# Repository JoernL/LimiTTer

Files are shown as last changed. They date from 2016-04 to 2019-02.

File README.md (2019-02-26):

# LimiTTer
Transmitter for the Freestyle Libre FGM system

With the LimiTTer you are able to transform the Freestyle Libre FGM system into a real
Continous Glucose Monitoring System (CGMS). That means that you don't have to manually
scan the sensor with the reader. The LimiTTer does this for you - every 5 minutes. It sends
the glucose value to your smartphone which must have the xDrip app installed. xDrip is really
a great and matured app for Android. It can send the glucose values to your smartwatch or
via Nightscout into the cloud. The most important feature is to having a night guard.
xDrip+ is an improved version of xDrip and now the default app for the LimiTTer.
You will find it here:</br></br>
<a href="https://jamorham.github.io/#xdrip-plus">https://jamorham.github.io/#xdrip-plus</a></br><br>
Click on "Download latest APK" or choose the "Nightly Snapshots" for the very latest ones.

Please note, that LimiTTer is NOT maintained by Abbott. It is a experimental DIY project.
You will built your own individual LimiTTer. So you are responsible yourself for what you
have built. I have opened this project here because it's a invitation for all developers
out there to improve the LimiTTer.

Feel free and join our chatroom here: 
***









***

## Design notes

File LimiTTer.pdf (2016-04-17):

DISCLAIMER: LimiTTer is a experimental DIY project. By building your own transmitter, you are responsible yourself for what you have done. The authors and maintainers of this project cannot be made responsible for any damage or actions.
Don't make any medical decisions based on the data of your sampled device.

Please Note: LimiTTer is not maintained by Abbott. It's only an experimental DIY guide.

Let's get started.

You will need the following things:

- Libre Reader (for starting a new sensor)
- Arduino pro-mini 3V 8Mhz
- USB to TTL Serial Adapter Module
- Solutions Cubed BM019 NFC Module
- HM-11 Bluetooth Module (Seeedstudio)
- Lipo battery >= 3.7V 220mAh 40x17x6mm (When BLE OFF enabled, 100mAh suffices)
- Lipo charger (Adafruit Mini micro-usb)
- Small power switch
- A box 40x40x12mm
- AWG 30 silicone-cable
- Soldering iron
- Helping Hand
- 2K epoxy glue
- Dremel like multitool with grinding wheel

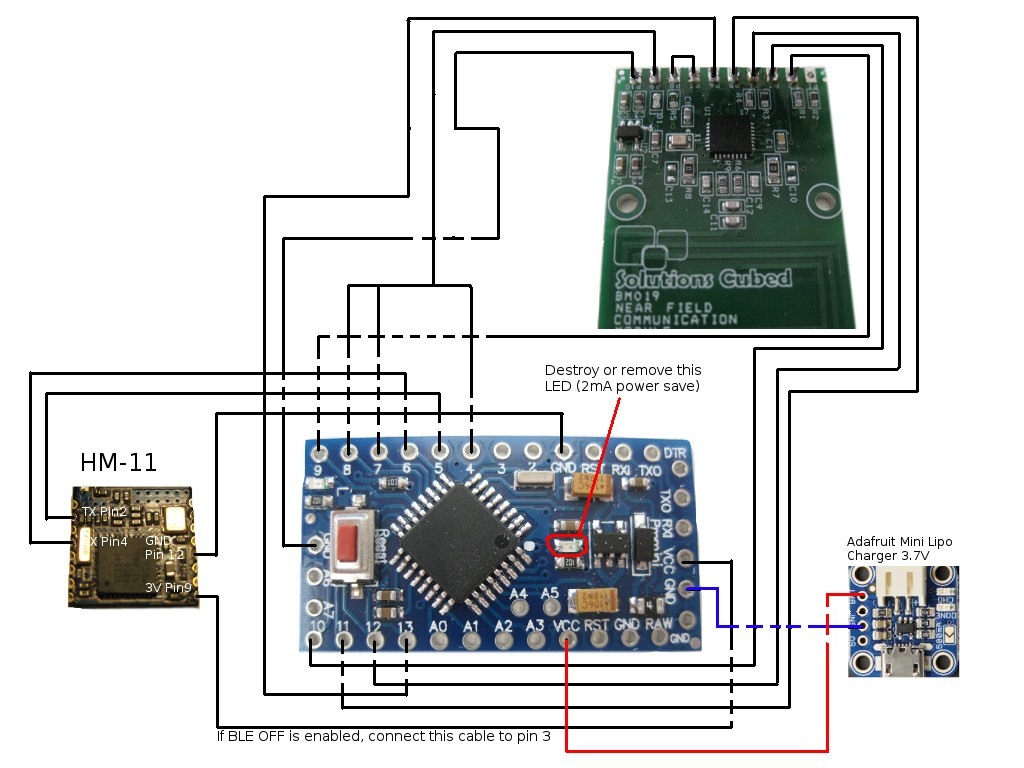
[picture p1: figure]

You may wonder why pin 4,7,8 are going into the Vin of BM019. It's because i need to power off this module completely and when it wakes up for reading and spi comes up, the power consumption raises to 80mA. So i just split this into 3 ports to spare the Arduino.

First download LimiTTer.ino and save it to your desktop.
Then you have to download and install the Arduino IDE. You will find it here:

https://www.arduino.cc/en/Main/Software

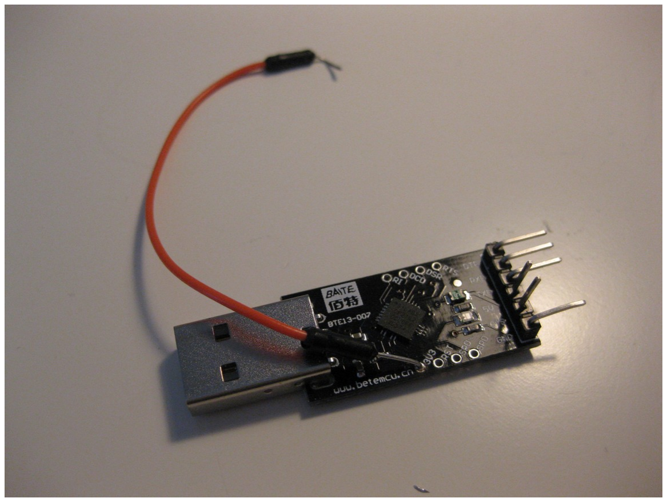
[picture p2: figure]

Start the IDE and navigate to the tools → board menu. Select „Arduino Pro or Pro Mini. From „Processor“ choose „ATmega328 (3.3V, 8MHz)“.
Now open the LimiTTer.ino file and prepare your Arduino:

Solder a cable to the 3V3 pin and bend up the 5V and CTS pins.

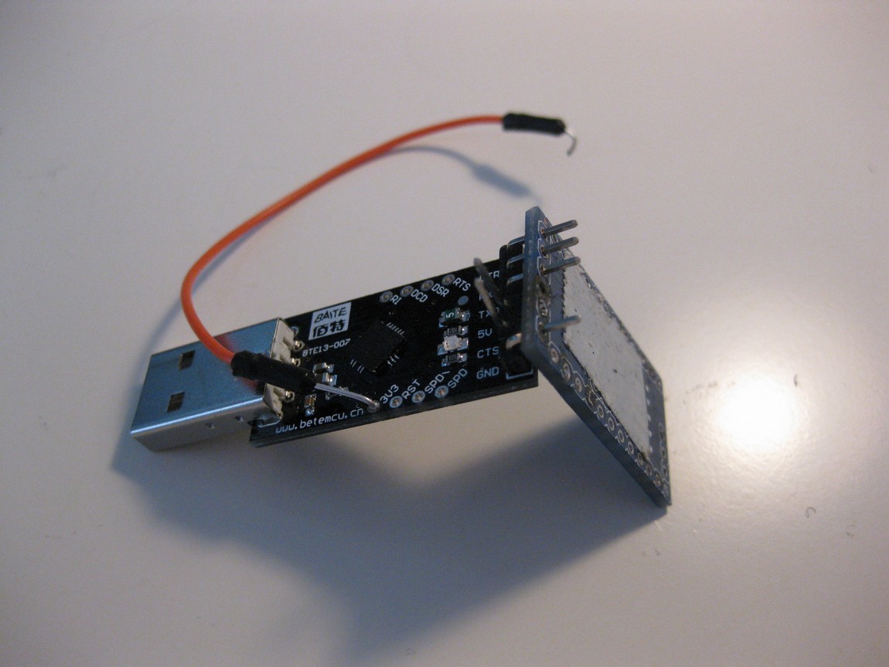
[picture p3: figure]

Plug the adapter into the Arduino and connect it with the USB jack
to your computer. Now you are ready for program the board. Click on the Upload button and hold the 3V wire on a VCC pin of the Arduino. Yes, it's a bit tricky. Of course you can temporarily solder it on that pin ;) When there is no error message and you see „Done uploading“ you can pull it out of the computer.

Now the hardware:

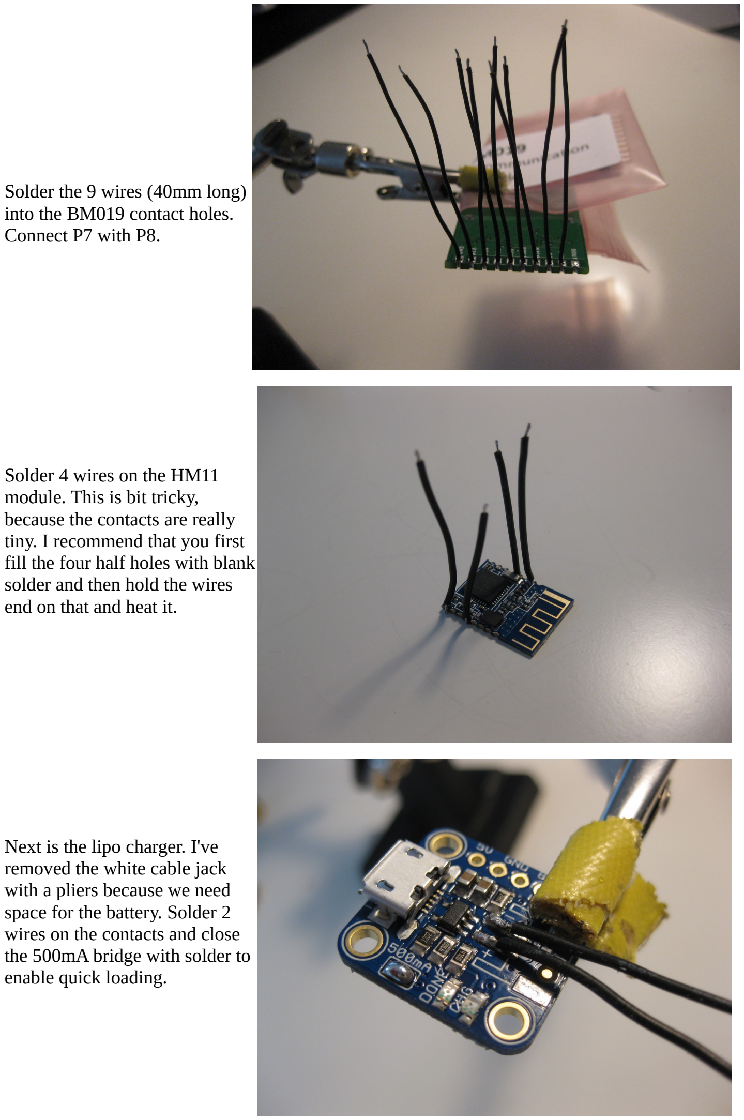
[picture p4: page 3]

Solder the 9 wires (40mm long) into the BM019 contact holes. Connect P7 with P8.

Solder 4 wires on the HM11 module. This is bit tricky, because the contacts are really tiny. I recommend that you first fill the four half holes with blank solder and then hold the wires end on that and heat it.

Next is the lipo charger. I've removed the white cable jack with a pliers because we need space for the battery. Solder 2 wires on the contacts and close the 500mA bridge with solder to enable quick loading.

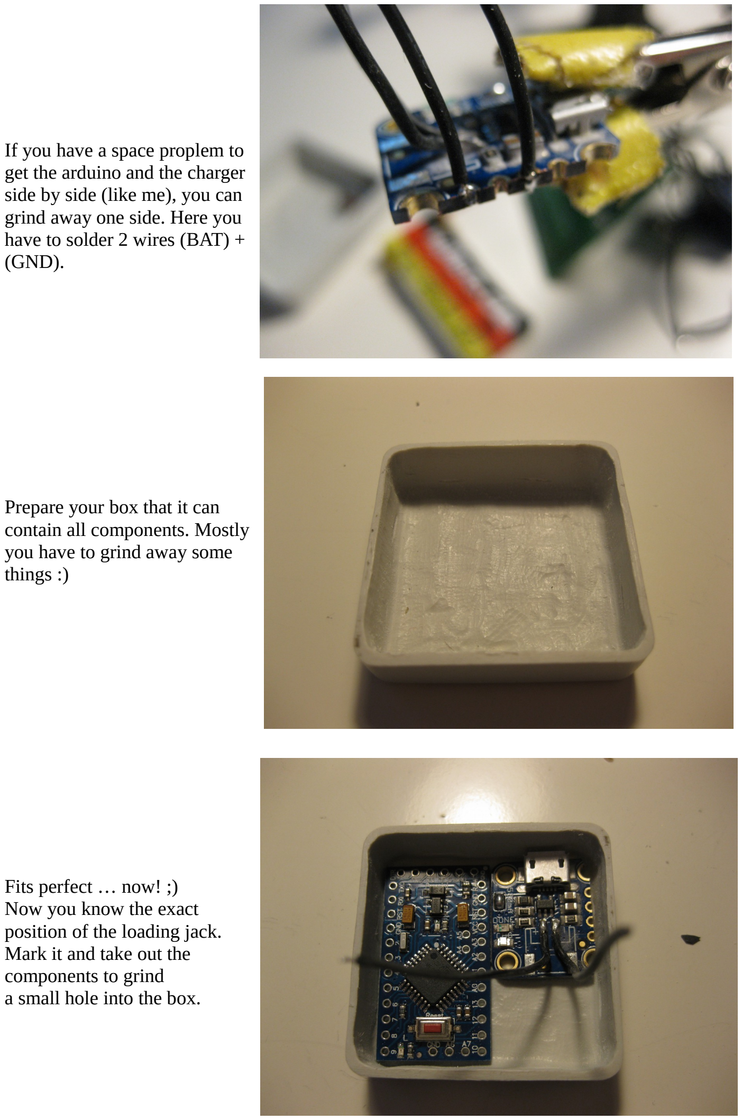
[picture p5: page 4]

If you have a space proplem to get the arduino and the charger side by side (like me), you can grind away one side. Here you have to solder 2 wires (BAT) + (GND).

Prepare your box that it can contain all components. Mostly you have to grind away some things :)

Fits perfect … now! ;)
Now you know the exact
position of the loading jack. Mark it and take out the
components to grind
a small hole into the box.

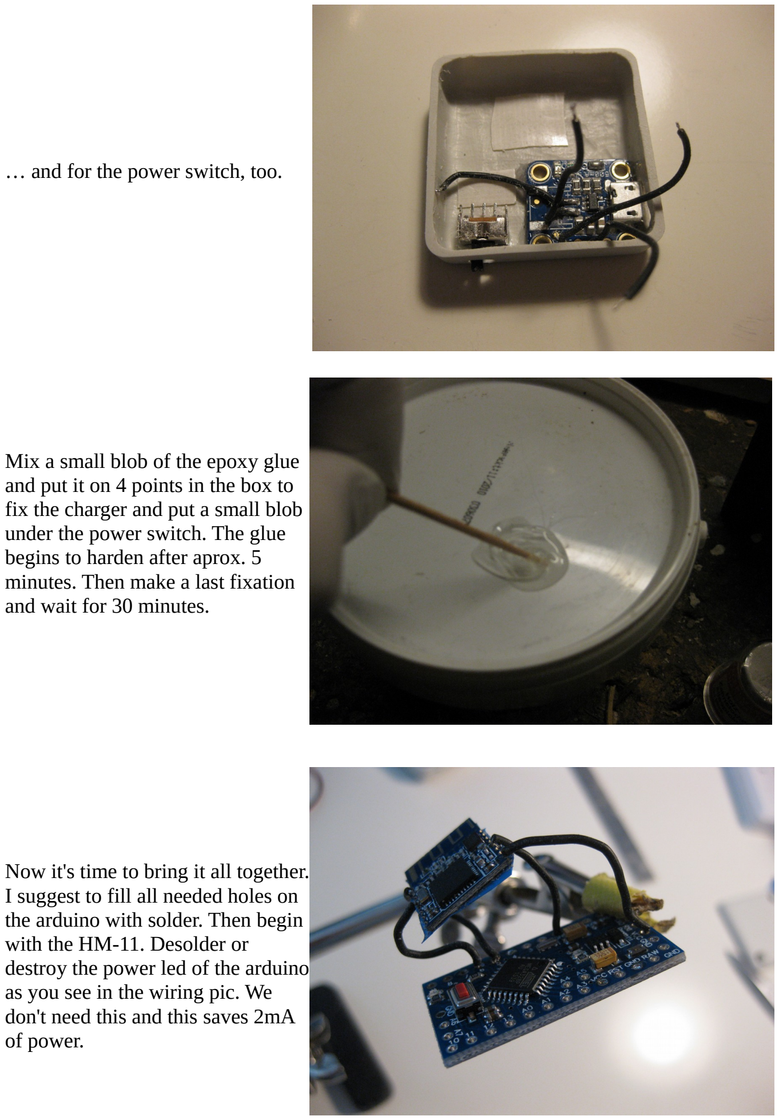
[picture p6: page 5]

… and for the power switch, too.

Mix a small blob of the epoxy glue and put it on 4 points in the box to fix the charger and put a small blob under the power switch. The glue begins to harden after aprox. 5 minutes. Then make a last fixation and wait for 30 minutes.

Now it's time to bring it all together. I suggest to fill all needed holes on the arduino with solder. Then begin with the HM-11. Desolder or destroy the power led of the arduino as you see in the wiring pic. We don't need this and this saves 2mA of power.

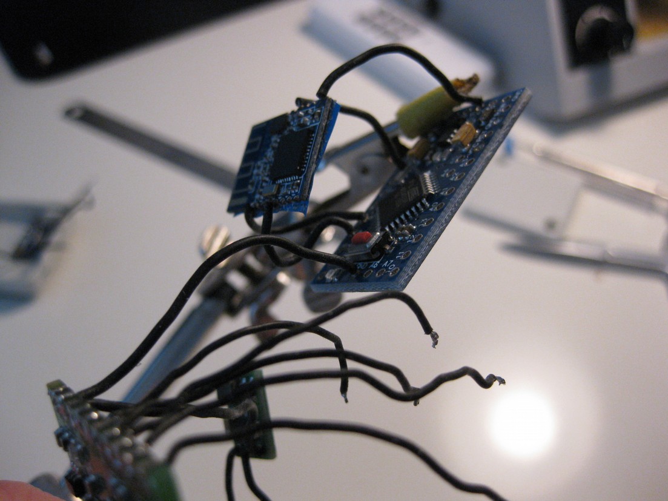
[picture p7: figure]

Then go on with the NFC module.

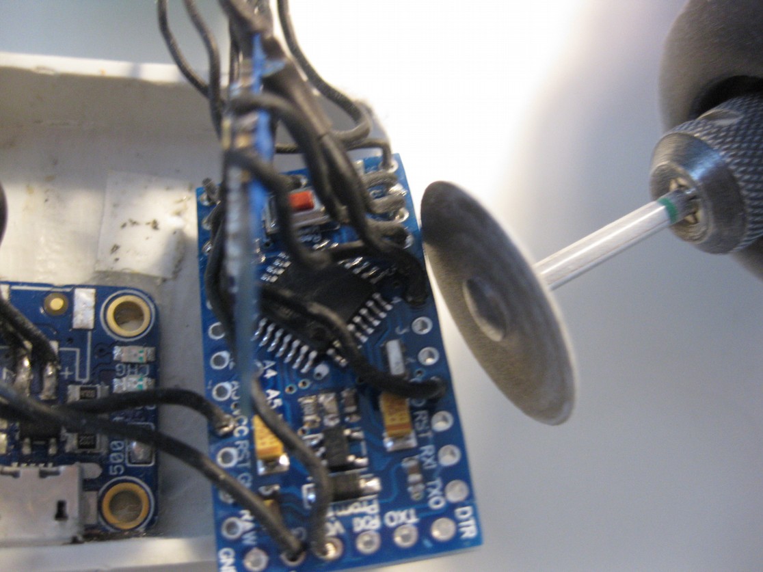
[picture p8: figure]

And now the lipo charger … You can grind the sides of the Arduino, if you have a space problem (like me).

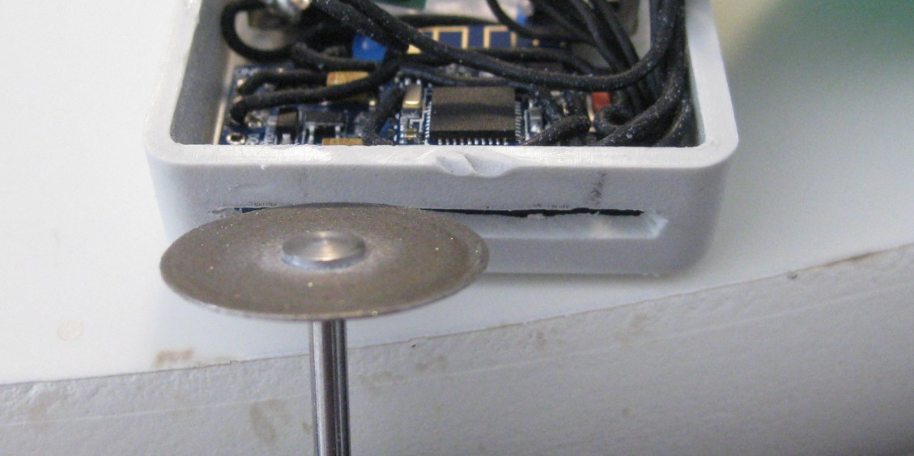
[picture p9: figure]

All 4 PCB's are now wired together. It's time for the recess.

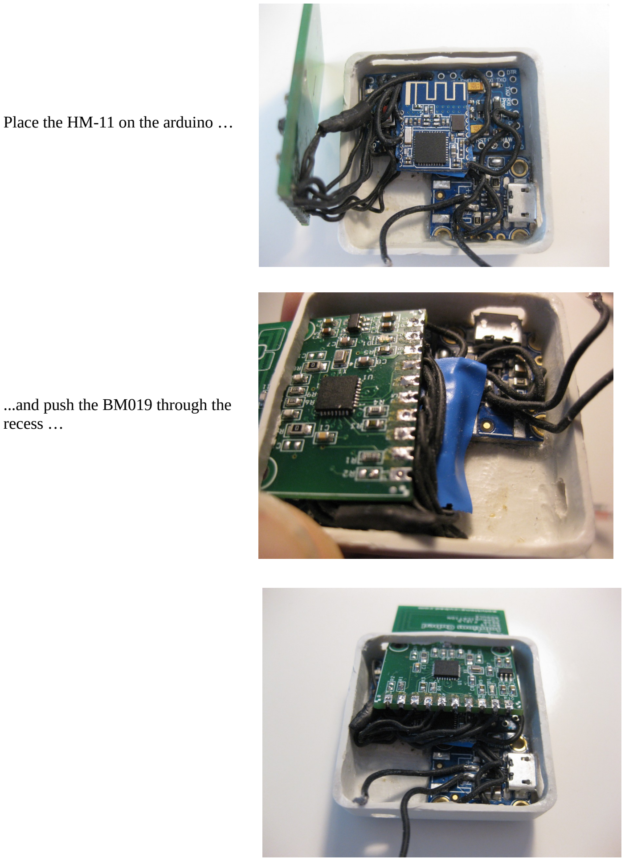
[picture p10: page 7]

Place the HM-11 on the arduino …

...and push the BM019 through the recess …

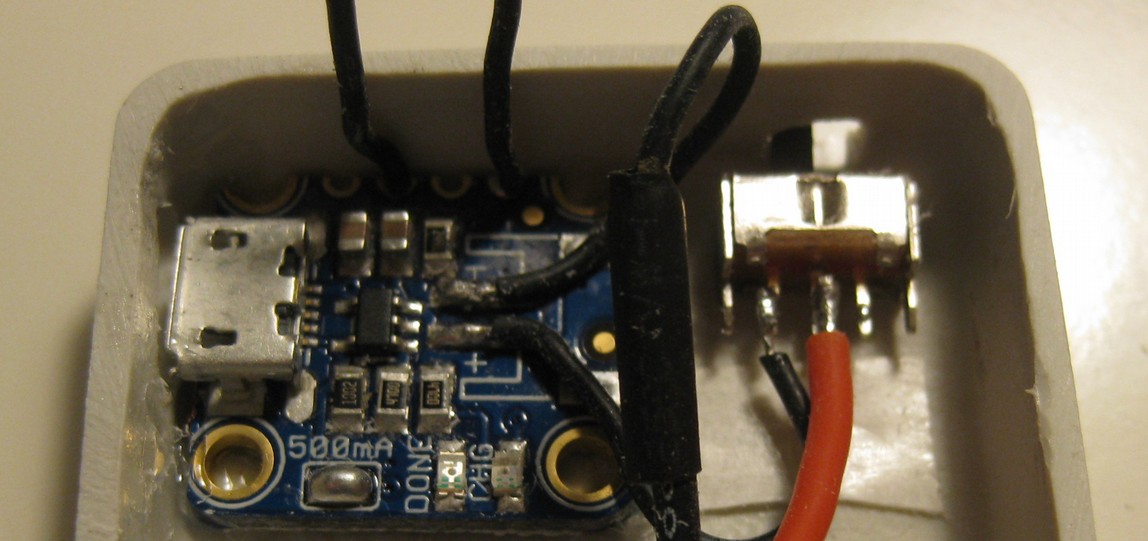
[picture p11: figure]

Solder the Lipo to the switch

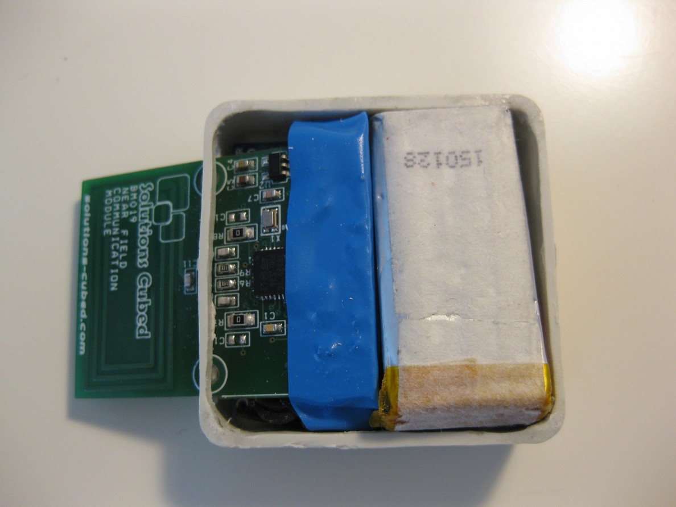
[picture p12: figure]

...and place it on the charger/ switch

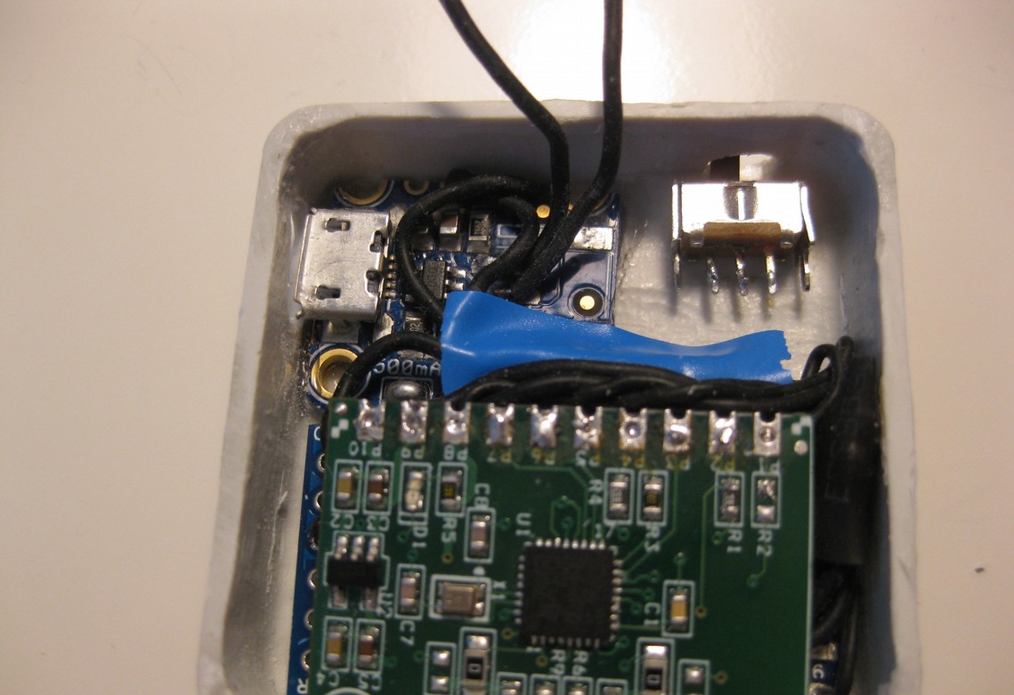
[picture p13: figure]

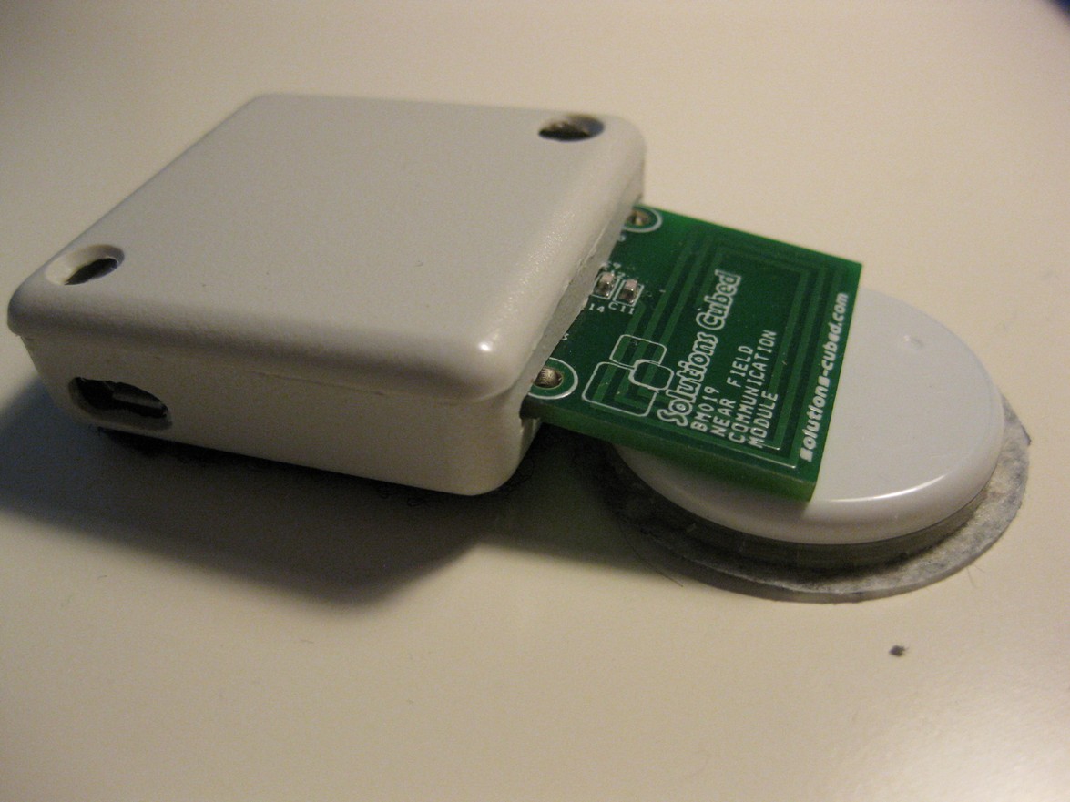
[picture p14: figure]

Close the box and fix the
lid with superglue on it's corner points. Add only tiny blobs of the glue.

To place and fix the LimiTTer on your skin near the sensor you can use Velcro tape or the very thin dual lock from 3M.

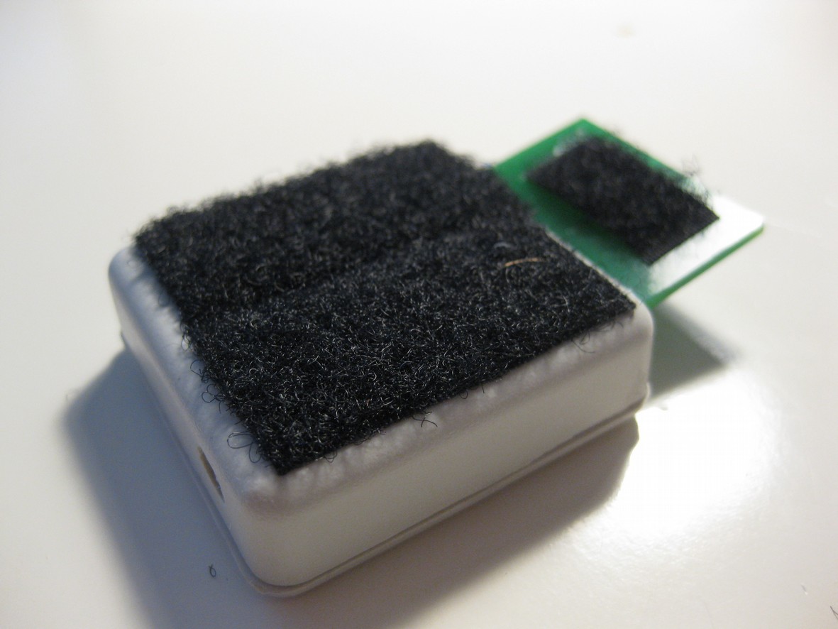
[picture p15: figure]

Turn on the power switch and place it near the sensor.
Finally download and install xDrip. You will find it here:

https://github.com/StephenBlackWasAlreadyTaken/xDrip/wiki/xdrip-beta

Download and install the latest beta .apk file. Maybe you have to enable the option to install apps from a unsave source.

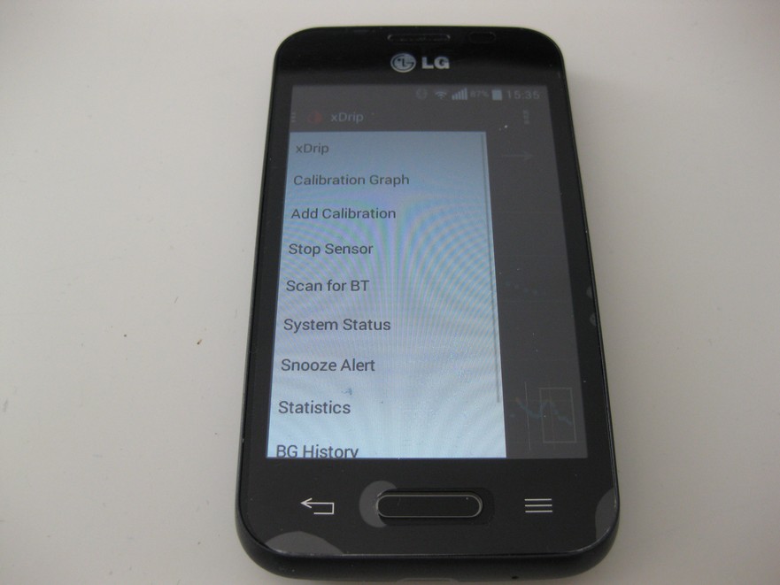
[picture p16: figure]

Then activate bluetooth on your smartphone and start xDrip. Click on the xDrip menu (left upper corner) and select Scan for BT.
Click on scan and you should see your box. If you don't see it, there is something wrong with your wiring … or you are using the BLE OFF wiring. Then it sleeps and will wake up the next 4 minutes … check it out and tap on scan several times.

Tap on LimiTTer and it will connect to it. After this you have to tap on Start Sensor. Just select a few hours in the past to avoid the 120minutes waiting. We don't need this. Now xDrip waits for 2 readings (10 minutes). When they are received you will see

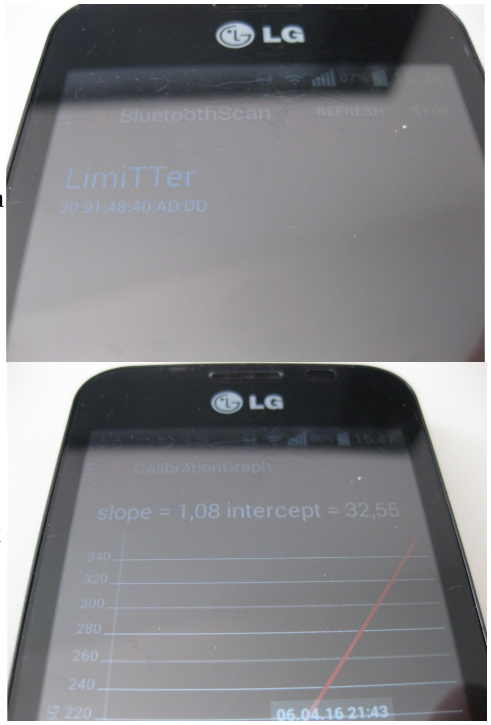
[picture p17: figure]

Enter 2 Calibrations. Tap on the menu and then on Add double Calibration. Enter your glucose value twice and tap on Done. Now xDrip should show you every 5 minutes a value.

Acquaint yourself with xDrip. It's a great and matured app with many features.
Have a look at the Settings Menu. With xDrip you can set an offset to the gluco value. That means if you know the difference between the libre reader and your real gluco from your meter, you can check the Calibration Graph and check the intercept value. As a sample my reader mostly shows a value that is -30mg/dl compared to my meter value. My intercept is 32.55. That means xDrip calculates
+32.55 to that value coming in from the LimiTTer
and then display it. You can change the intercept
with Add Calibration. So when you have entered a calibration
and checked the intercept and it doesn't match yours, tap on Override Calibration, re-calculate the value and check the intercept again.
When you take off the transmitter for charging and apply it again it is sometimes necessary to tap on Forget Device in the System Status menu. After this you have to Scan for BT and tap on LimiTTer again to reconnect the device.

The LimiTTers power consumption is 8.8mA @ sleep because Bluetooth is always on. With a 220mAh lipo you must load it every 24hrs. Charging time: about 40-45min. If you have Android >= 5.x you can try to solder the BLE OFF circuit and enable all lines in the Limitter.ino file that contains BLE OFF. Have a look to the sketches description. The problem is the reconnect after turning off Bluetooth completely. With that circuit, power consumption is 0.16mA @ sleep for 4 minutes. Then it wakes up and waits 60sec for the reconnect. If this works stable for you, then you can use a smaller lipo (80-100mA) and reduce the heigth of the box. (2-3mm thinner).
So check it out ...

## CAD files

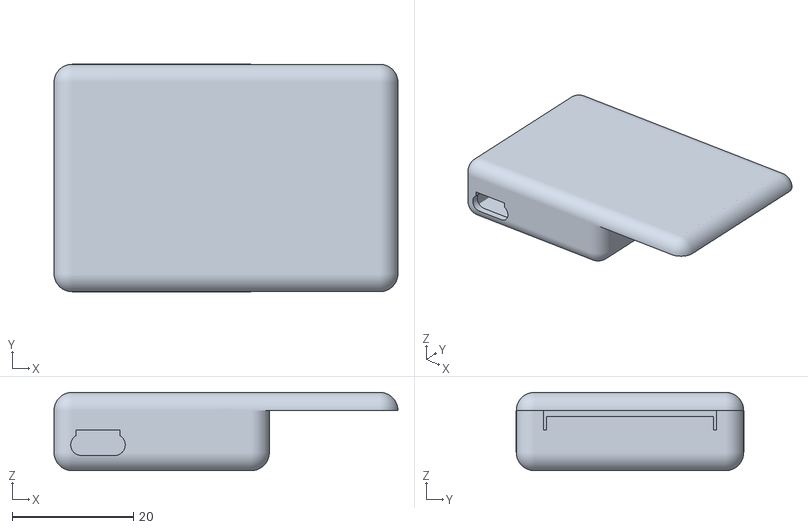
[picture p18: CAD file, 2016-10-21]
case-3dprint/case_assembly.stl
56.7 x 37.5 x 12.9

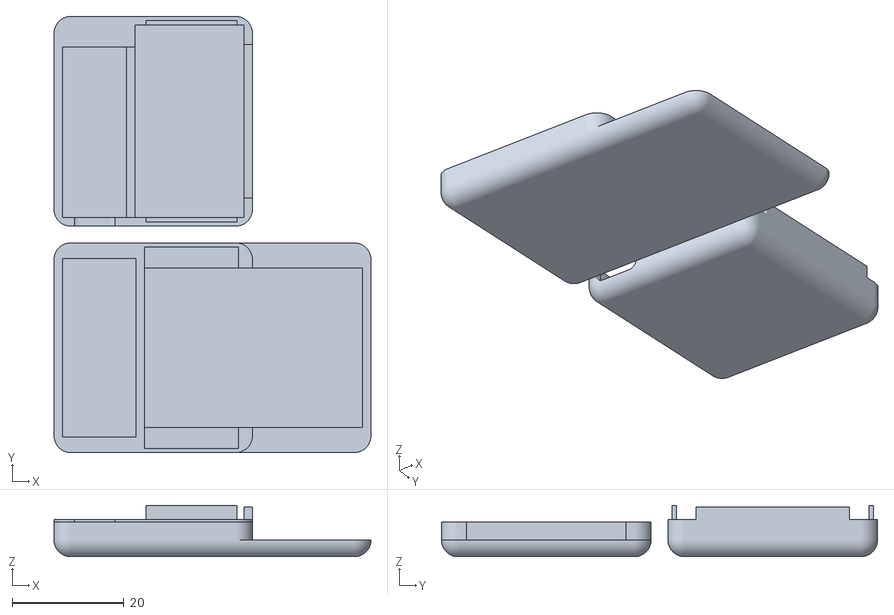
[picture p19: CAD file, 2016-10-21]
case-3dprint/case_print.stl
56.7 x 78.0 x 9.20

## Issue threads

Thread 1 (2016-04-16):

LIMITTER

pedrojrr, 2016-04-16:
Hola mi nombre es Pedro y soy padre de un niño Diabetico que usa el freestyle libre. Primero quisiera darle mi enhorabuena por el desarrollo del proyecto ya que llevábamos tiempo buscando algo parecido.  Estoy deseando que comparta su diseño para poder probarlo en mi hijo sobre todo por la utilidad de guardián nocturno.  Gracias por su tiempo y dedicación estoy convencido que seremos muchos los padres que se lo agradeceremos. Espero tener pronto noticias suyas

holmberg81, 2016-04-16:
English would be more easier to understand.

berniemcintosh, 2016-04-21:
I speak a little spanish - here is a rough translation:

Hi, my name is Pedro and I am the father of a Diabetic boy that uses the Freestyle Libre. First I want to give my congratulations for developing the project since we have been waiting some time for something like this.  I want you to share the design for us to be able to use it with my boy, above all, for the overnight watch. Thanks for your time and dedication. I am convinced that there will be many of us parents that thank you. I hope we have more updates from you soon.

JoernL, 2016-04-21:
@berniemcintosh , you are welcome.

JoseRobotnik, 2016-04-24:
Congratulations for developing such as great project.
I ordered some of the components of the limitter in aliexpress.com, except the BM019 NFC2Serial. Is there any other NFC2serial compatible dongle to replace it?
Many thanks

JoernL, 2016-04-24:
I dont't know any other working module.

libxmike, 2016-04-26:
Joern, is there any trick to pair with Android?
I have Nexus with Android 6 and can't pair, not with the default pin or any other,
can't see it in xDrip, any ideas?

To see the name "Limitter" in Settings-> BT, I had to change the code to:
ble_Serial.write("AT+NAMELimitter");

JoernL, 2016-04-26:
Settings -> Apps -> xdrip -> permissions. Enable location services.

tim2000s, 2016-04-26:
Thanks Mike. I'll try that. I can see the HMSoft device in xDrip without that mod and it pairs, although it didn't transmit any data. Do you have the correct baud rate set?

Sent from my iPhone

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

birdfly, 2016-04-26:
Hello,I  am a T1D for six years and user of a free style libre,I just  wonder that LimiTTer(the hardware )could interpretate the Tag-data  or transmit  the raw data to xDrip directly.For I have used several libre apps ,the value they read are different from the official reader.

tim2000s, 2016-04-26:
Okay, my progress so far is that I've built the LimiTTer, and that all the components communicate. I can confirm the Arduino is speaking to the HM10 as, with the earlier tweak, I was able to get the module renamed correctly.

The assembly then connects to xDrip on the phone successfully.

At the five minute intervals, the NFC card comes to life and I am assuming it scans, and I see the green LED flash on the Arduino. What I don't get is anything in xDrip. Nothing is showing up.

I welcome any ideas on what I might need to change. The baud rate is set to 9600 as is the default on my HM10. Just not picking anything up and transmitting it.

Sent from my iPhone

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

JoernL, 2016-04-26:
You are not able to start a sensor in xdrip? The 2 start readings don't come in?

tim2000s, 2016-04-27:
That's right. Whilst xDrip sees the Bluetooth and connects, and I see the BM19 trigger, I'm not seeing anything come in on the two start readings. I'm running android 5.1.

Sent from my iPhone

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

JoernL, 2016-04-27:
The Hardware Data Source in xDrip settings must be set to "Bluetooth Wixel". Maybe you have changed this?

JoernL, 2016-04-27:
@birdfly  as yet, it only reads the last saved reading from the sensor and send it to xDrip, which modify the raw value through a slope and an intercept and then displays it at it's graph. I'm working on it now to find out how the original reader can precalculate the readings when glucose rising fast? At this moment the raw reading is the nearly the same but the LibreReader shows a very higher value. Maybe a hidden dynamically slope multiplier in the tag? Didn't find it yet.

berniemcintosh, 2016-04-27:
Joern,

I commend your work and find it most interesting.  My own feeling is that I think I prefer to see a raw reading from the Libre, with a simple adjustment to put it into mmol/ml. I think the need for predictive algorithms is perhaps not as great as the stress that some put on them.

My take on it is that knowledge and context are the most important thing. I know that the interstitial glucose level lags behind BG as measured with a finger stick. This in itself lags behind venous level. Just as we are all used to the lag in BG fingerstick readings, maybe we should all get used to the lag in interstitial readings.

If I see that the Libre raw reading is fairly constant, then I can have good confidence that it reflects the reality. Constantly high, maybe I need to take a small amount of insulin. Level of 4.0 for half an hour and I'm about to exercise then maybe a little glucose is in order.

If the Libre reading is rising fast, I can judge for myself if there is a single reading that is a little out of step or if there is a trend. If there is a trend, then I can see how sharp the trend is, and for how long it has been there. I can look a the picture and let my brain fathom it  out using its massive parallel processing power and pattern recognition abilities in order to understand what is happening. An actual, predicted level that matches a BG fingerstick I don't believe is my ultimate objective. I can guess at what it might be and it will probably be as correct as any complex multiple derivative based algorithm.

Perhaps the trouble with the algorithm is you don't quite have a grasp of what the algorithm has done. At least with raw data I can use my experience.

Likewise when BG is dropping. I see that the raw data is plunging from 13 to 10 to 7 to 5 in 25 minutes. I think I'm not concerned that I don't have a predictive current value equivalent to BG fingerstick. I want  some glucose please, NOW. Even though it says 5.  My experience tells me what is going to happen next. Not that I have such dramatic incidents too often, but it can happen.

So adjustment of data with slope and intercept yes, but predictive algorithm like the built in one - kinda looks good but not necessary.

As you know occasionally the Libre refuses to give you a reading.  Wouldn't you just love to know what the raw values are that led to that decision. Well I guess we do now with the BM019 but I've yet to see it for myself.

Sorry - not trying to put you off - its good to have a predictive algorithm too. The more info the better. J

Cheers

Bernie

tim2000s, 2016-04-27:
Definitely set to the correct source. That's what is so odd.

Sent from my iPhone

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

SugarBots, 2016-04-27:
Tim- have you tried using a Bluetooth tool like Adafruit Bluefruit LE or BLE ( I use the ones for iOS) to confirm the BLE packets?
And have you successfully paired the BLE in both android settings and xDrip? I haven't had issues with getting the data to display on xDrip, just that the mmol conversion needed to be added in.
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
tim2000s, 2016-05-02:
Update: For some reason after a restart, it is working. I'm getting data on xDrip from a live Libre sensor.

Sent from my iPhone

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

libxmike, 2016-05-02:
@tim2000s what did the magic?
I slowly give up, my stick with my working Simblee solution and iOS app.

JoernL, 2016-05-02:
@tim2000s, i think it will. But the modules length is 43mm. I've chosen the pro-mini because its only 32mm. Every mm counts ;) It must be as small as possible cause you wear it every time.

JoernL, 2016-05-02:
@libxmike, tomorrow i will upload new code. Maybe this will fix your problem.

libxmike, 2016-05-03:
@JoernL thanks, will be great if it works, and thanks for your time you investing in it.

sean75, 2016-05-03:
Dear Sir,
I write from Italy, south Italy,and my son is a diabetic boy ten years old.
He use frestyle libre and I have a lot of interest for limitter.
Can you give me some information to build it?
Sorry for my bad english.
Thanks
--
Inviato da Libero Mail per Android martedì, 03 maggio 2016, 07:24AM +02:00 da libxmike < notifications@github.com> :

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

tim2000s, 2016-05-03:
I think it depends on how you wear it. If it's in a neoprene sleeve, fewer devices and lying next to the BM19 is fine.

I'm trying to avoid the box!

Sent from my iPhone

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

tim2000s, 2016-05-03:
Look forward to this!

Sent from my iPhone

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

LibCGM, 2016-05-03:
@tim2000s box is not an optimal solution, I designed and 3D printed one, it is too bulky
http://imgur.com/8nMsZuy
I may design one with round edges, shallow/flat and reassembles you arm - arc shape, the frame is 1-1.5mm thick

SandraK82, 2016-05-03:
we are exploring the option to use flexible boards embeded in Silikone for the bluereader. The only bad thing is, that firmware over the air has to work correct, or the Silikone must be openend. Loading will be wireless, probably qi std. Batteries might be two rechargable li-ion coins cells
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

LibCGM, 2016-05-03:
@SandraK82 Silicone my be the same problem as Abbott glue, maybe warped in a fabric to avoid Silicone - skin contact? but again it wont be on 24/7 like the Sensor so you skin can breath.
Silicone is ok if you want to have it on 24/7 w/o taking it off, Qi charging was also my consideration but in addition to micro USB in case you are not near a charger. It has to be moist but not waterproof, you don't want to swim or shower with it.

SandraK82, 2016-05-03:
Yes it might be, but so far it seems to be the best option we can think off. For the usecase as libre reader, the solution does indeed not be waterproof, however we are targeting a broader audience (like Industrie) with the bluereader. Therefore it needs to be resistente against Shock, fluids, chemicals and needs a a easy handling.
My current protoype setup is only warped in  insulation tape and needs a 5v breaboard Adapter for charging (currently no lipo charger with usb port, order does not arrive). I found fixing the the board with medical tape (Leukosilk) works best for me. I applied a curapor plaster over the sensor to further protect my skin ( i got burns from an unprotected contact of my boards once). I Experimente also with arm cases for mp3 players, bandages and a custom sawn armband but i was not able to lock the board over the sensor for a day without squeezing my arm to tight.

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

tim2000s, 2016-05-03:
I'd been looking at the flexible PCB options too.

The issue I'm running into with all of this is it starts to remove the DIY aspect and we run into where liability lies. With the current xDrip kit, the user has to solder a component in place and do the software upload.

Is an OTA software upload by the user enough to alleviate liability risks?

Sent from my iPhone

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

SandraK82, 2016-05-03:
As far as we have Look into the liability aspect we found that a generic device should have no liability or guranties besides from working safely within the specifications made by us. Our device does not support xdrip upload with the original firmware, not even Interpretation of the libre data, it just acts as an ble to nfc gateway for many different nfc card and tag types…
So if you decide to use an app which utilizes the bluereader library to Connect to an bluereader and then communicates with the libre sensor and shows an Interpretation of the data obtained, or if you opt for replacing the open source bluereader firmware with a own diy firmware which can talk directly to a xdrip, then this should be beyond the scope of our liability :) at least i hope so and got a correct understanding of the different national and international laws

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

LibCGM, 2016-05-03:
@SandraK82 here is my try to fix it with Velcro http://imgur.com/yWh2rkH , I can even sleep on it but its far from optimal
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

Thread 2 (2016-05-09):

the xDrip experimal

birdfly, 2016-05-09:
Hello

I  know that the xDrip is developed for Dexcom G4,and I find some codes to Interpretate the data from Wixel BT  devices ，but our Limitter is desighed for Freestyle Libre and the data from two devices may be different ,have you modified the codes for the data send from Limitter .

JoernL, 2016-05-09:
Yes, the LimiTTer code converts the value into a raw dexcom value by a simple multiplier.
Dexcom raw values are much higher.

birdfly, 2016-05-09:
so this function is accommplished in the hardware or the xDrip modified for Limitter

JoernL, 2016-05-09:
It's accomplished by the Arduino.

birdfly, 2016-05-09:
if I want develop an app which have more features than xDrip （for example add the insulin and food etc）,how can I receive the data from my Limitter

holmberg81, 2016-05-09:
Hi
some one now if LimiTTer works to Nexus 5x thinking to buy  one. :)

Doing the last part now off LimiTTer hope it works to the weken.

Martin
Den 9 maj 2016 15:53 skrev "birdfly" <notifications@github.com>:

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

roppenheimer, 2016-05-13:
Can you post where you purchased the various components from. Most of them are no problem but I have been unable to locate a suitable box.

Thanks, I really appreciate the work you have been doing on this.

JoernL, 2016-05-14:
I've purchased this one:

(http://www.voelkner.de/products/290989/Miniatur-Kunststoff-Gehaeuse-1551qgy.html)

JoernL, 2016-05-14:
@birdfly, your app should receive a simple string with 3 values via BT. Then cast that values into an int, long, or what you like.

roppenheimer, 2016-05-14:
Thank you. I have now found a local supplier of this casing. Hammond Electronics manufacture a range http://www.hammondmfg.com/dwg9.htm

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

jolaca01, 2016-05-16:
Hi Joernl, Thanks for the cases link!!. I really like your chosen case but I would prefer to leave the NFC reader protected inside the case (cutting it)  in more or less this way:
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

So, I guess for this, a longer case would be needed, as I don't have yet my components here, what do you think: 1) would the NFC reader be able to read if I close the case this way? and 2) 50x50x20 or 50x35x20?? PLease, let me know your thoughts!

holmberg81, 2016-05-16:
Hi I have in case. 47x45mm and 15mm
And batteri 250mA
Den 16 maj 2016 11:27 fm skrev "jolaca01" <notifications@github.com>:

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

jolaca01, 2016-05-16:
Hi Holmberg81 have you got a link to your case or could you share a picture? Are you planning to cut down the case in the same way??

holmberg81, 2016-05-16:
New box in 3 days. Send you new one then.
Den 16 maj 2016 12:07 em skrev "jolaca01" <notifications@github.com>:

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

JoernL, 2016-05-16:
@jolaca01 , maybe with your design idea the case should be 3d printed. Then the front area could be solid where the BM019 sticks in at the bottom. The exterior of the tongue (BM019) can then be added with velcro tape that sticks on the sensor. But the wall thickness must be thin at the tongue. Good idea! :) Yes.

jolaca01, 2016-05-16:
Thanks JoernL!! Definitely it would be great to have it printed but I have ordered a pair of cases and cutting down and retouching one I'll try to get a first version sorted out. Then,  it would be nice to have a neat perfect dimensions  3d printed case. ;-)

EvertKlevert, 2016-05-23:
Is there anyone who could make me one? I'd buy it from you, for a nice price. I live in the Netherlands. (Oh and I'm certainly not that techy to make one by myself....)

jolaca01, 2016-05-25:
Hi @EvertKlevert, I'm still waiting for an NFC module to build the one for my daughter, I hope it will arrive this week. If everything goes well I wouldn't mind to build one for you but it's @JoernL designed so he may have something to say, I mean I  wouldn't want to bother anyone. ;-)

EvertKlevert, 2016-05-25:
Hie @jolaca01 Thanx for the offer! We're talking about the LimiTTer for freestyle, though?

(I get confused by sites talking about the xDrip and this LimiTTer. The xDrip is only Dexcom?)

I hope @JoernL will approve. This would be *the* most interesting way in making the Libre a CGM.

jolaca01, 2016-05-25:
@EvertKlevert  don't get confused, xDrip is also used by @JoernL LimiTTer to pass data via BT from the Arduino mini to your mobile and then from there to your  Nightscout site. And yes, the thing is to convert the FS Libre to something similar to a CGM device.

jolaca01, 2016-05-25:
To be clear, I mean xDrip is an app (on your mobile) that receives data (in this case form the LimiTTer) via BT and can send it via internet to your Nightscout site.

EvertKlevert, 2016-05-25:
Forgive me my confusion,, in mij search I found [this site](http://xdripkit.co.uk/) where a receiver is being offered, and it's called xdrip. So not an app, but a transmitter.

EvertKlevert, 2016-05-25:
In addition: the ^^^mentioned site which offers an xDrip hardware-set, this one is used for the dexcom g4.
Mmm. In my quest for 'The Answer Of Knowing Everything On How To Make A CGM From Libre' I still haven't found the universal answer/guide.

JoernL, 2016-05-25:
@EvertKlevert , for dexcom systems "xdrip" mostly stands for both - hardware + app. The LimiTTer hardware is using the same "xdrip" app as the dexcom hardware (Wixel). In future ... xdrip app will be able to display data from a medtronic cgm system, too. One app for all systems. Only problem is, that xdrip app is Android only till now.

JoernL, 2016-05-25:
@jolaca01 , design like you want :) My design is only a reference design. With the instructions pdf you are able to make a copy of this.

jolaca01, 2016-07-08:
Hi, just wanted to thank JoernL again as his LimiTTer is working great for my daughter. I also wanted to share the final design I've used. Taking advantage of the fact that when you use Velcro the total height increases a little bit over the Libre sensor, instead of making a recess in the case, I think it's better to make a cut in the top of the case just for the NFC reader but keeping it inside. Thus, we can place half LimiTTer together with the Libre sensor, using less space. Here I attach a photo of it, though I've used a 50x50 case and it's a bit too large for my daughter's skinny arm. Nevertheless, I think it may work fine with a 40x40 case design.
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

NFCole, 2016-07-09:
I had this idea, too, but i wasn't sure if the nfc is strong enough... Looks great, well done ;)

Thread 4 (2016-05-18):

The Official App Released

birdfly, 2016-05-18:
the official app Librelink have released but it read a sensor which must be started by the app，so boring it is⋯⋯⋯⋯

if someone decompiled the app and transplant the algorithm that app uses to LimiTTer，something will change

SandraK82, 2016-05-18:
@birdfly not that easy to do :) the also is in native compiled code embedded within the app, so you can choose between reading arm or x86 disasembly

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

Closed 2016-12-09.

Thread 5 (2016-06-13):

Other NFC modules?

mattiastoyra, 2016-06-13:
Hello!
Really love this project of yours.
I try to build one for myself but ran into problems. I cant seem to get hands on a Solutions Cubed BM019 (out of stock whereever I look). I live in Sweden
This is my very first time trying to build something using Arduino and I hoped it would be as simple as swapping the BM019 for any other NFC/RFID module.
I bought this out of E-bay http://www.ebay.com/itm/MFRC-522-RC522-RFID-Radiofrequency-IC-Card-Inducing-Sensor-Reader-for-Arduino-BE-/191371999374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
and just tried to find the corresponding pins.

 But I cant get it to read Libre sensors, the bluetooth connects as it should though so I figured its the NFC module.

Do I have to rewrite all the code for this specific module or what am I doing wrong?
Can you recommend any other NFC module that are compatible with this project?

Thank you!

JoernL, 2016-06-14:
This one does not work. You have to wait for the BM019. Don not worry ... the distributors have  noticed a huge increase of pre-orders and have ordered much more from SolutionsCubed

Verticoe, 2016-11-13:
Hi,
first of all thanks for your wonderful work. Right now, I am in the process of building my own LimiTTer for my girlfriend. Most of the parts already arrived. Unfortunately, I made the same "mistake" than mattiastoyra, buying an RC522.

So far, I was able to map the pins on the RC522 to the ports of the Arduino Pro Mini. Amongst other, I did the mapping with the help of this project here [https://github.com/AndreaBruno/OpenBtNFC/wiki](url). There is a nice sketch in the middle of the site.
Anyway, due to your answer I hesitate to actually solder the parts together. I am rather inexperienced with Arduino and also taught myself how to solder just recently and I don't want to make experiments and want to follow your instructions as close as possible. Thus, I ordered the BM019 from Solutions Cubed.

Yet, I wonder if you made your own experiences with the RC522? Did you try the RC522 module before switching to the BM019? Why exactly does it not work? Is it something with the energy consumption?
Is there a chance to make it work by modifying the code of the LimiTTer.ino?

Also, when the connecting the the BM019 to the Arduino Pro Mini, the Vin goes to 4,7 & 8. Did you just solder three pieces of wire together?

Thank you for your effort!

JoernL, 2016-11-13:
@Verticoe , RC522 does not support ISO 15693 NFC. On my current LimiTTer i have tested powering the BM019 by only one pin for a long time - and it works without any problems. So i can recommend this to save space in the case.

BabarRehman, 2017-12-16:
Hello, I have a problem, I am trying to Port your code to ESP32, my inventory command fails because the value returned is not 128, however it does detect the BM019 cause the values in rxbuffer change, I don't have experience in microcontrollers, can you help me with identifying the issue?

Closed 2016-12-09.

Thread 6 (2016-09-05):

Code Limitter

PatrickAPT, 2016-09-05:
Hi
I am working for a research group in Norway with the aim of developing an artificial pancreas.
We are currently us the Freestyle Libre to monitor some of our experiments.
To improve this monitoring and to simplify our set-up, we are intersted in using the LimiTTer to read the Libres.
However, to be able to do so, we have to fully understand the code executed by the LimiTTer. Unfortunately I am struggling with the function Read_Memory(), where the LimiTTer reads the Libre.
I know that the LimiTTer gets a string of trends from the Libre.
The big question is now how does the LimiTTer decide which is the "right" value to forward to the xDrip?
This is very important to us, as we have to know if and to what extent we can trust the data submitted by the LimiTTer.

Furthermore i built already a LimiTTer and ran a few tests. We are currently sampling every 30s and at a distance of up to 2cm between the Libre and the LimiTTer. It is working quite well, but i am getting outliers every so often (ex. constant values of 6.5mmol/l and suddenly one measurement at 12mmol/l).
I have a few ideas about those outliers:
1. Faulty bit in either NFC or Bluetooth communication
2. Oversampling of Libre (no data ready to be transmitted by the time of reading)
3. Wrong decision by the LimiTTer algorithm
What's your opinion? Any suggestion from your side for those outliers?

Please contact me under patrick.c.bosch@ntnu.no
And if you're interested in our project: www.apt-norway.com

Thank you very much for a swift reply and have a nice day.

Patrick

JoernL, 2016-09-05:
Hi Patrick,

The outliers issue sounds strange to me, because i have never noticed such fake readings from my sensor or have not heard from another one about such a problem. So i guess it must be the 30s scan interval. In the Read_Memory() you see the "invalid trend check" comments. I have built in that check to avoid such outliers. To answer your big question: The LimiTTer fills an array (trend[j]) with all scanned trend values and compares lastGlucose variable to currentGlucose variable (trend-pointer -1). If the lastGlucose is higher than currentGlucose it knows, that glucose is falling and fetching the smallest trend value from the array. Conversely glucose is rising. An exeption is the apex case. I have find out that the libre reader sometimes displays a rising value even when the lastGlucose is higher than currentGlucose. Then the structure of the trend values are a bit different and the LimiTTer is also taking the highest trend value to emulate the original libre reader as effectively as possible. For your APS project - if you need smoother and slower acting sensor values just take the glucosePointer value. But if you need faster acting sensor readings, don't touch the Read_Memory() function. Please let me know if a change of the scan interval solve your problem.

PatrickAPT, 2016-09-19:
Hi Joern

Thank you for your swift reply and sorry that it took me so long to reply.
As for the outliers, I am currently very busy, but i'll check if it's due to the short sampling interval and let you know once i know more.
And thank you again for the detailed explanation.

Have a nice day

Patrick

JoernL, 2016-09-20:
Another reason for your outliers could be that the antenna is a little bit away from the sensor. I had determined this for myself and had some outliers, too. Check it out ...

trixing, 2016-10-15:
I think the error checking in Read_Memory should actually be done per packet which should give a more robust model.  My proposed fixes for this would be

https://github.com/trixing/LimiTTer/commit/5cb9caf37c167098ec83bd5d51a693a61d57de51
https://github.com/trixing/LimiTTer/commit/5b54b0b063502964f575c4c9f02a2f7c18278726

Let me know if you want these as pull request...

PatrickAPT, 2016-10-29:
Hi

Thank you for the Software-Update.
I will load it onto my Limitters first thing on Monday and run some tests during the week.
And once I had a look at the data I’ll give you some feedback.

Regarding the pull request, I ‘m not very experienced with GitHub, but if it makes things easier, please do so.

Have a nice weekend

Patrick

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

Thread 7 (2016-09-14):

Lipo

mrs404, 2016-09-14:
Where can I get a suitable lipo battery in the UK. Any help appreciatedesk.

jotomo, 2016-10-02:
Try the Gitter channel (see main repo page), there are more people listening.
I was hunting down a 110mAh Lipo some weeks ago, got one but it turned out be broken. The 110mAh ones are tricky to come by these days, I didn't find another source.
I ended up using a 550mAh from Amazon which fitted into the big version of the LimiTTer and which has been running for 6 days now and still has 46%.

Closed 2016-12-09.

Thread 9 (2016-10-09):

Battery Life of Sensor

berniemcintosh, 2016-10-09:
Hi,

I am reading the sensor every five minutes as per the original code. In the last few days of the sensor's life the NFC reading has become unreliable. I am waiting to verify this behaviour on the next sensor.

A likely scenario is that the Sensor's on-board battery is getting weak after so many reads. Yet it doesn't seem to affect the official reader to the same extent.

Does anyone else report this behaviour ?  Any ideas on optimum time between reads ?

Incidentally, I substituted the Arduino and HC10 combination for the very small RFDuino board (see link below). It programs like an Arduino but the BlueTooth  is built-in,  Sleep mode is phenomenal - I can manage very low average current consumption.

[https://evomedia.evothings.com/2014/11/rfduino-chip.jpg](url)

For anyone interested I also dispensed with the NightScout links. My unit uses BLE advertising packets to broadcast to a number of nearby receivers. One is an alarm only - no LCD display.  The others have permanently lit LCD displays and one is at the bedside, the others dotted around the house.  I wanted to get away from using phone, and prefer to have these devices around the house - keeping an eye on G level is just like just like using a clock.

Regards

Bernie

berniemcintosh, 2016-10-11:
Well the problem continued and finally the unit stopped working altogether.

I found the problem. I had made a slot in the case like most other folk have done. Through the slot the BM019 was positioned to be over the top of the sensor. Well C12 on the circuit board is a little exposed and had obviously been knocked against the side of the slot, displacing it before eventually it disappearing alogether.

I replaced it with another 220pF capacitor and this cured the problem.

Cheers

Bernie

Closed 2016-10-11.

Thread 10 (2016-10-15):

Verify that sensor is still active

trixing, 2016-10-15:
As far as I can tell the code doesn't verify right now if the value is actually current and valid.  I have tested with a few expired sensors and will show the last valid value.

JoernL, 2016-10-21:
Yes, it doesn't. I think it should read out the internal timer to send the remaining sensor time to xDrip.

trixing, 2016-10-25:
Yes, I actually have code for that already.  Just need to polish it a bit
more.  But it helps that the values will be all zero after 2 weeks.

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

--
Jan Dittmer <jdi@l4x.org>, http://l4x.org

JoernL, 2016-12-10:
Verification included now. After getting the same value 5 times && sensor expired counter is > 14days, serial output will display an expire hint. xDrip will show nothing then.

Closed 2016-12-13.

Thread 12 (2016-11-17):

How much energy does the Libra sensor draw?

acollien, 2016-11-17:
There's a little battery (silver or something?) in the sensor - or so I read - which allows it to run for 8 hours and collect data. It gets charged via the NFC process with a phone or the reader (I assume).

So, I figure, for you to make this project work, you'd need to know the minimum energy the sensors need to run, right? or the amount required to charge the sensor's little internal battery?
I'm guessing it's minuscule - a percentage of a fraction of a watt?

SandraK82, 2016-11-17:
The battery is not charged through the nfc readout. In fact I can now confirm that the battery expires at some point, rendering the tag useless as the reading of the tag is then not reliable possible. Some of my first analyzed tags dating back to February/march 2016 are now dead.

Von meinem iPhone gesendet

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

Closed 2016-12-09.

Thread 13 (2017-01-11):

Extend use of FreeStyle Libre sensor

renno-bih, 2017-01-11:
I'm glad to see projects like this. As this sensor can work only for 14 days it is very expensive for diabetics.
Is there any way to extend life of this sensor and still use it with LimiTTEr after 14 days. Looks like battery is not problem but Abbot forces you to buy another one.

BenY1, 2017-01-15:
I would also like to open one up and inspect it. I feel it may have some sort of internal clock that counts down once the tag is active to the reader. Its likely not possible to change anything. If its got an internal clock then short of modifying the clock on a nano level is impossible. They have us by the balls. I will strip one down soon to see how they made them.

JoernL, 2017-01-15:
I have opened (milling) an active sensor and tried to do a quick restart by pull and push the battery for a second - without success! It immediately stops working.

mantas-done, 2017-02-25:
In LibreLink app there is one interesting sentence:
Be aware that travelling into earlier time zones could shorten your sensor life if you are near the end of your sensor wear period.

So maybe the life can be extended by changing to different timezone?

Source:
https://www.librelink.com/support/getting-started/new-sensor

nicolasrk, 2017-09-29:
@mantas-done I think there u have a point. I didn't probe what happens if u move back ur date on the reader when is almost to finish the sensor time. Anyway I think the sensor should have some logic and flags to avoid this kind of situation. But is a good point to try a hack.
I'am pretty sure the life time of the sensor is mostly defined by commercial reasons. (for sure there is tech reason like, oxidation of sensor, battery life time, etc, etc. But 14 days sounds really arbitrary IMO.

d-scott, 2017-10-24:
FYI some people have had success getting readings from the sensor after the 14 day period using the Glimp app on Android. Check the comments from this blog post:
http://www.diabettech.com/freestylelibre/freestylelibre-more-than-14-days-glimp-a-third-party-libre-reader-app-with-a-difference/

Perhaps the same can be done with LimiTTer?

darren060673, 2018-02-21:
Ok, so I'm new to github, but have been a very keen hardware tinkerer for many years. I have opened up several libre sensors and managed to download Ti datasheets for the family of proceesors. The chip has a reset pin than appears to be tied down to -ve with a resistor and capacitor of as yet unknown values. There is also a thermistor coupled to one of the processors ADC inputs. I am currently trying to figure out how to potentially reset the device.
Would be greatful of and software help, as I am purely a hardware guy.

darren060673, 2018-02-27:
I have just learned today that the USFDA have only approved the sensors for 10 day use, therefore it's got to be a software/firmware switch, most likely determined by the reader/starter. Has anyone managed to start a new sensor from a Non Abbot  App, like Glimp or Xdrip? apologies if I'm asking stupid questions, but I feel there has to be potential to  hard reset the processor.

valentinser, 2018-03-05:
Hello, just found this topic. I wanted to say that Glimp cannot start sensors. As far as I know, only the official Abbott FreeStyle Libre App or the Sensor Reader can start a new sensor.

waltsteinchen, 2018-03-07:
I read through the specs .. and imho the chip has a MSP430 as core and is completely programmed OverTheAir at startup (=enabling the sensor with the reader), imho it's a general purpose chip for reading data through NFC from TI.. nothing really special for Abott. I guess! that this is the reason that you cannot enable a sensor with the handy app because the risk that the app would be reverse engineered was considered too high. I also guess that the entire expiration programming is determined during that programming stage.  Thought a while why it is possible to read data from the sensor for >14 days, ~1 day or so... but the oscillator on the device is probably not very exact .. so they let it run for a little longer time and do the exact limitation in software. At least I would do that ;-) again .. all above is basically guessing.

SandraK82, 2018-03-07:
The chip is not a standard, but very similiar to a standard nfc chip from ti. The application is factory preloaded and the activation is just setting something via nfc. This is not only done by the official apps and already reverse engineered by the people who provide glimp-s.

Once activated the chip locks Write access and Starts the timer, this Runs usually 14 days and a half currently for me (European sensor). There are reports of longer running
sensor from other countrie, but nothing concrete yet.

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

valentinser, 2018-05-01:
Hello, 
I think the 10 day period vs 14 day period might be related to different regulation and aplicable laws.

  On Tue, May 1, 2018 at 20:56, fernandezfj<notifications@github.com> wrote:
All,
My son has been using FreeStyle Libre sensors/reader that we purchase from Europe for the last 2 years.
Yesterday we attempted to read/initiate a US purchased sensor with the European reader and I received an error indicating the sensor was not compatible (I'll try to post exact error later).
FreeStyle Libre from Europe lasts 14 days and have a 1-hour warm-up instead of US version which lasts 10 days and has a 12 hour warm up period, which is ridiculous.

—
You are receiving this because you commented.
Reply to this email directly, view it on GitHub, or mute the thread.

fernandezfj, 2018-05-01:
Hello,

I read part of the FDA approval, it seemed like Abbott was playing it safe and extended warm-up period and shortened the dates to be able to show even better data. I didn't see a restriction from the FDA per say...
Since I have both type of sensors I will try to take them appart and share pictures, but I don't anticipate finding any hardware differences. My guess is taht the software in the reader can detect the sensor it is authorized to work with and will dictate the warm-up and life of it.
I finally got the prescription approved for my son in the US, and was very dissapointed to learn about the limitations.

glaucoqs, 2019-04-12:
Hi.. I'm from Brazil, and diabetic... Studying the sensor, the activation is in the moment when you open the new sensor and put 2 parts together... The pins of sensor, short the circuit, and let's battery energy starts the counter. Supposing the memory is for 8 hs and the sensor works about 14 days..  the counter is for the number of times the chip save the middle of 3 measures (1/min).. in total.. because in last day, with the app glimp, it's repeat in grafic..

I think the sensor can be used for much time... It's only a electrode sending and measuring the energy back.. to insert again in skin, can be used the needle in applicator...

cadcoke5, 2019-04-30:
The electronics are not the main issue that limit the lifespan of the sensor. Rather, it is the chemistry of the sensor and the body's own activities that affect the sensor filament that goes into the body.
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
charebl190, 2021-04-08:
Can someone send it for me by mail? Pls
Zaarourc45@gmail.com i can't manage to build the app and my sensor expires on Monday pls

HimenBluepixel, 2021-07-28:
@cominixo i have a Libre 2 Canadian sensor. I want to activate the sensor with Android custom code. Do you have an idea what could be the byte array or command need to send for activate the sensor. I tested your demo code with Non US libre 1 and its working very well.

Please let me know if you have any idea for same.

cominixo, 2021-07-29:
I have no idea about internals of libre 2s, don't have them yet

Himen007, 2021-08-23:
@cominixo Do you have an idea about how to activate and get glucose data of the Libre Pro sensor ?

Harry5533, 2021-11-05:
I've been using Libre pro for the past two years and able to extend it for 28 days now. sometimes it breaks before reaching 28. But any day after 14 is of great help.

Need help with it. DM @ https://www.instagram.com/bornunic/

Works only with Libre Pro

maujah, 2021-11-23:
Hello

I have a sensor that finishes its cycle in a few days, unfortunately last weekend I lost the reader where the information of the last three days was left,
Is there a method to retrieve the sensor information, or is there no longer a chance?

Harry5533, 2021-11-29:
hi maujah,

If u have nfc phone u can retrieve it

Thanks

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

RjayG, 2022-05-23:
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

hi,  i use libre 1 but not familiar with xdrip as i do not use that. do i really need to use that if I reset the sensor? if so, can you teach me how to use it/calibrate? just a quick step by step guide should be ok or if you can point me to a resource to read should be fine as well. thanks!

Harry5533, 2022-05-24:
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

-----------------

@olektee  - reset should be done couple of hours before expiry. thats is 13th day after completion 20 hours of usage is safe. Personally i have tried resetting it even after 3 days and it works good. i use Libre pro from India.

mohdmunaf, 2022-10-07:
@Harry5533 Hi, I wanted to activate Libre Pro sensor through Android/iOS app. It would be great if anyone has code snippet.

foxisoft, 2023-01-23:
Hi,
Do you have a solution to extend Libre2 sensor?
Thanks

7 oct. 2022 17:33:30 mohdmunaf ***@***.***>:

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

cadcoke5, 2023-01-23:
I never found one.

TanyaStoman, 2023-01-23:
If anyone ever do find one please share with us

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
--
Tanya Stoman

Harry5533, 2023-01-23:
Hi JoernL/LimiTTer,

This works for libre pro not for other versions.

Thanks
H

On Mon, 23 Jan, 2023, 10:40 pm TanyaStoman, ***@***.***>
wrote:

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

evrynet1, 2023-02-15:
@cominixo

> Yeah if it's past that mark you should just do it with the next one, but you can still do it after it officially expires, just not after the extra 12h or so it has.

If you are up to I would be happy to send you some Libre 3 sensors to have a look and maybe also sponsor you a bit :) to see if you can extend the lifetime of the sensors, let me know, thanks.

sharbel101, 2023-04-15:
has anyone found how to extend the life of freestyle libre 2??

foxisoft, 2023-04-25:
Hi,

Now I'm using a Libre 2 sensor, will expire in 2 days. I will try to
extend it.

Could you send me the right procedure to do this? Step by step. And the
right app to do. I've installed on my mobile device (Samsung S10)
OpenLibreNFC. I don't know if is the right/good app, please clarify my.

About to use Libre 3, I'll be happy to use them to try to restart them.
You could send me some of them. If you agree this, I'll send you my home
postal address.

I have had this disease for 7 years and with the help of this type of
sensors I manage to keep glycosylated hemoglobin around 5 mg/dl

This is my email and phone:

+40727058708

***@***.***

***@***.***

Thank you and good luck

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

ddranchi, 2023-05-07:
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

HI Harry - does your code also activate the Libre Pro sensor?

alija312, 2023-05-24:
managed to extend libre2( French)with openlibre NFC don't know how long it will last.  I use Juggluco as a reader.  Immediately after the expiration I reset and it works.
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

evrynet1, 2023-05-24:
@alija312 how about libre 3? any luck with that?

alija312, 2023-05-24:
> @alija312 how about libre 3? any luck with that?

I don't use libre3.  I do not know.  It's a good combination for me with Libra 2. juggluco and G-Watch.

foxisoft, 2023-05-24:
Hi
How do you use juggluco to restart Libre2? Or what do you use to restart Libre2?

24 mai 2023 14:11:06 alija312 ***@***.***>:

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

alija312, 2023-05-24:
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
i used juggluco to measure.  and extended it with OpenLibreNFC

olektee, 2023-05-24:
Could You please do some more explanation step by step how to extend this ?
:)

śr., 24 maj 2023, 18:44 użytkownik alija312 ***@***.***>
napisał:

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

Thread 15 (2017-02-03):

Update components

tonichub, 2017-02-03:
HI! I'd love if you can update the list of components , because i can't find the right battery and bluetooth module..  And there is an error on description on module bluetooth its said "if you have Android 4 connect this cable to VCC instead of pin 3 and disable all "for Android 4"  lines in the .ino file"  so .. connect cable for android 4 or android 5 ?
Thank you!

daniel515, 2017-02-06:
i heard that the adafruit bluefriut nrf8001 LE (bluetooth card) should work but i dont know.
Hope you keep on trying. please update me if you get any info. Sorry for bad english best regards Daniel

BenY1, 2017-02-18:
Any battery will work, even a non rechargable such as a cr2032 but lipo recharchables are convenient. Shipping lipos is difficult within Europe however Chinese companies are generally very flexible in posting batteries. Try Ali express.
Frankly your as well rooting an Android 4 device to at least Android 5 as later android versions are better at re awaking bluetooth devices from sleep not to mention the energy consumption is less.
Hardware does not need updating. You need a hm17 or hm 11 module as we know that these are compatible. Arduino pro mini with an ATmega chip 328 / 3.3v / 8 MHz. It hardly matters which type of arduino mini you buy as long as its the above spec.
Configuring the Arduino IDE just select AT mega 328 and select the serial interface port on your pc

apabari, 2017-08-11:
Just checking in - has anyone found a list of components?  I asked a similar question but haven't heard back yet.

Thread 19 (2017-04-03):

Case

daniel515, 2017-04-03:
Hi! Great job with the LimiTTer.
I Wonder if you could please publish the CAD file for the case?
Sorry for bad english Best regards Daniel

steeleorama, 2017-09-17:
I just completed my device, using the following case.

https://www.aliexpress.com/item/free-shipping-plastic-enclosure-control-box-1-pcs-51-51-15mm-plastic-electronic-project-box-junction/1998549081.html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

All components fit fine and no grinding was required.  Only modifications to the case was to cut the openings.  Also, case has holes to insert a strap to hold the device on.

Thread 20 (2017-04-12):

Different Hardware

nigelkeirross, 2017-04-12:
Hi
(Excuse me if this is the wrong place to ask questions).
I am interested in building one of your LimiTTer for my Libre. I have wondered if you have considered  using either the arduino pro micro rather than the mini?
Also would it be possible to use the Blend Micro  (http://redbearlab.com/blendmicro/) arduino that has built-in BLE, and is 18mm * 42mm, slightly larger than yours, but has BLE built in.
Thanks

JoernL, 2017-04-22:
The pro-micro uses more power than the pro-mini.

mattmholliday, 2017-07-24:
I would also love an alternative to the BM019 as its is very expense to source in Australia.

MityaKLG, 2018-03-19:
Hello! Thank you very much for your product. I would like to clarify whether it is possible to use X-NUCLEO-NFC05A1 http://www.farnell.com/datasheets/2339631.pdf  instead of BM019 ?

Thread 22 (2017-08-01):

Hardware Component List - Canada

apabari, 2017-08-01:
Hello,

I'm in Canada and just pre-ordered the Freestyle Libre.  (I'm currently using a Dexcom G4 and an xDrip, with the xDrip+ app, but eager to try out the Libre and LimiTTer.)

Was hoping to get some guidance on some of the components -- as I'm not sure where to get this items:
- USB to TTL Serial Adapter Module
- Lipo battery 3.7V 100mAh 28x12x5mm

I can see most of the others are available on www.robotshop.com/ca.

Could anyone please post a link to where these two items available for purchase?  Just want to ensure I get the right components.

Thanks,
Andy

keencave, 2017-08-21:
I would suggest to look on Aliexpress - there you will find: https://de.aliexpress.com/item/Free-shipping-1pcs-FT232RL-FT232-FTDI-USB-3-3V-5-5V-to-TTL-Serial-Adapter-Module/32460118879.html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,searchweb201602_5_10152_10065_10151_10068_10193_10194_10304_10307_10137_10060_10302_10155_10154_10056_10055_10054_10059_100031_10099_10103_10102_10052_10053_10142_10107_10050_10051_10320_10321_10322_10326_10084_10083_10080_10082_10081_10177_10110_10111_10112_10113_10114_10180_10312_10313_10184_10314_10315_10316_10319_10078_10079_10073_10186-10050,searchweb201603_17,ppcSwitch_4&btsid=f2024a6a-3c47-45fe-8698-6a6f34b31a6b&algo_expid=1da2e6b0-e177-42e5-9eaa-16fbc435a8c7-0&algo_pvid=1da2e6b0-e177-42e5-9eaa-16fbc435a8c7 and a lot of LiPo batteries which all should fit.

apabari, 2017-09-14:
Thanks

Closed 2017-09-14.

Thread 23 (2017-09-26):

Xdrip+ does not read any data

MazingerZTTR, 2017-09-26:
Good afternoon,

First of all i'd like to thank JoernL for sharing this project!
I have built two limitters with exactly the same devices (HM11) explained in pdf instructions but i can't read any data from sensors. Xdrip+ connects correctly by bluetooth as you can see in screenshots but then, nothing happens. I have used the latest arduino code in github but it can't read the sensor.
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

I also have read this "forum" and restarted the mobile phones (even i have tried with 3 different mobile phones but i had exactly the same issue).

I have checked the wiring twice in both Limitters.

Thank you for your help!

chinflon, 2017-11-08:
Hello @MazingerZTTR,

I am having the same problem, LimiTTer connects to xDrip+ but it gets stuck in "Please wait. 2 readings are needed".

Did you manage to solve it?

Also I found something kind of odd. In the Bluetooth collector status I see 'Glucose data from:' and it gets glucose data once but never updates so even if the Bluetooth connects every 5 minutes glucose data does not update.

@JoernL any idea? Thanks for your shared design by the way, great work!

MazingerZTTR, 2017-11-08:
Hi chinflon,
I used Lbridge code in arduino (https://github.com/keencave/LBridge) and connected it by serial to read the output. I could see that it wasn't reading anything from NFC and resoldered al connections using new AWG 30 wires. Now is working right.

chinflon, 2017-11-08:
Thank you, I will check that.

chinflon, 2017-11-08:
Anyway I think it should work since every 5 minutes I see the NFC reader green LED flash, so I assume the wiring is ok.

@JoernL
@MazingerZTTR

chinflon, 2017-11-18:
Thank you very much @MazingerZTTR I did as you suggested and worked perfectly!

cqrendo, 2018-03-21:
@chinflon when you say that you did what @MazingerZTTR says you mean that you change to LBridge or you just resoldered with AWG 30 wires or both?

waltsteinchen, 2018-09-27:
Had the same issue, was bad soldering ..
Turned on the LED each 5 minutes but finally data were broken ;-(
How to debug ?
A very helpful utility is the app "NRF Connect" (used it on another handy in parallel). This allows you to see the bluetooth packets comming from the Limitter device, ...the data field should contain the value.
In my case it was 0x00.

Just start the scanner.. wait until your device sends something and the press on RAW.. it should look something like the attached picture. Hope this helps
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

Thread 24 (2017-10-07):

NFC Aerial?

M1che1l3, 2017-10-07:
Hi there,

I am about to start my first attempt at putting anything like this together.  I plan to build this with the arduino primo core [to](https://store.arduino.cc/arduino-primo-core) reduce size a little.  I was originally planning to keep the two poker-chip sized discs separate and connect them with a wire (rather than stacking them) so the part with the nfc reader could be worn on top of the libre sensor and the other part be worn next to it to reduce the added height.

I am not experienced with this sort of thing, but I was wondering if anyone has tried adding a nfc aerial to increase the space it can be worn away from the libre sensor? I was thinking if it had a range of up to 0.5m-1m the arduino primo core could possibly be worn like a badge or button on clothing or even a necklace or earring in a 3d printed case if it had a little more reach?

Thanks,

 Michelle

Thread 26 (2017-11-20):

Broke PIN4 on HM-11. PIN5?

mierea, 2017-11-20:
Hello,

And thank you for this awesome project.
Can I use pin 5 instead of pin 4 on the HM-11?

I cannot find in code where you use this pin?

Thx.

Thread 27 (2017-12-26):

Ideas to port this to ESP32 ?

waltsteinchen, 2017-12-26:
The ESP32 could replace the ATMega easily and has built in Bluetooth so one module less needed in the end.. Any brain-work already done into that direction ?

renaudrenaud, 2018-01-10:
It could be quite easy to do the job, especially with micro python. Maybe latter, I want to build one as indicated before to think on another version. I also have a 3D printer and plan to design a box.

waltsteinchen, 2018-05-30:
Wow, phantastic! .. can we grab the code somewhere ?

idoroseman, 2018-05-30:
still a work in progress...
see https://bitbucket.org/roseman/freestyle-libre-monitor/src/default/

melanrz, 2018-08-08:
idoroseman,your sketch reset esp32 every reading

idoroseman, 2018-08-10:
hi @melanrz, it goes to deep sleep after each reading to conserve battery power. wakeing up involves a reset. is that what you mean?

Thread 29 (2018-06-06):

Libre Pro Sensor

Archana-Balan, 2018-06-06:
Hi,
I've been working on developing the Limitter device in India. We only have the "Libre Pro" sensors available here which stores complete data of 14 days.
 The sensor stores 15 minute trend data in one buffer and 14 days of historic data in the remaining memory blocks. I'm able to read the 15 minute trend data correctly. However the sensor NFC  tag contains only 256 blocks and can store only 4-5 days of historic data. The remaining data is shown as factory locked. Hence I'm able to read only 4 days of historic data
Any suggestions on how I could read the historic data of remaining 10 days ?
Thanks !

daclaw2k, 2018-07-09:
Hi Archana-Balan,
I have also tried using the Limitter device with the Freestyle Libre Pro but was unable to get any values at all into xDrip+! How were you able to get current trend data?
I have been able to get my hands on a few sensors from India so am happy to test anything.
Thanks :)

daclaw2k, 2018-10-03:
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

Hi Archana-Balan,

Any updates on how you are going? Did you manage to get this working at all? I'm using Glimp with SW3 at the moment with the Libre Pro, working ok but xDrip+ is a lot better.
Thank you very much :)

amit2411amit, 2018-10-25:
hi archana ji.. i have got the protocol to read sensor n return bytes.. can we communicate

daclaw2k, 2018-10-26:
hi @amit2411amit , I am still using the Libre Pro with sony SW3/Glimp app.
I have also built a Limitter and am happy to help with anything. Would like to get it working with xDrip+!

amit2411amit, 2018-10-27:
@daclaw2k pls connect amit2411/at/gmail/dot/com

daclaw2k, 2019-05-06:
FYI this has now been resolved. I have tested this successfully.

Comments from @keencave
Please find the updated LBridge code V1.1.01 here:
https://drive.google.com/open?id=1RLxzbgu5Y2GPyd2cUklRKI-TU94QK5Fg
Please use the Arduino IDE 1.8.9. The INO need to have the Libre2 library "L2read.zip" installed as a zip library with the IDE. Some minor fixes. Added support for Libre Pro (and Libre H). Any test result welcome. I had only an expired Libre Pro for test.

ipsita1917, 2020-09-09:
Hi.. I am using a Libre pro with miao miao 2 and would like to use xdrip. Will this be possible?? Please help!

ipsita1917, 2020-09-09:
@daclaw2k Hi.. I am using a Libre pro with miao miao 2 and would like to use xdrip. Will this be possible?? Please help!

deepakthakur143, 2021-01-13:
@daclaw2k I am also working on the LibrePro sensor and not able to find the History section offset and limit. Also not sure of how many bytes the total data is. Can you help please ?

daclaw2k, 2021-01-19:
> @daclaw2k Hi.. I am using a Libre pro with miao miao 2 and would like to use xdrip. Will this be possible?? Please help!

Hi @deepakthakur143, sorry I can't help, I am not a programmer and didn't write the original code. @MarakM60 (creator of droplet) helped decode it, I just sent some raw logs through to him. Have now moved over to a dexcom g5 as it was much more stable for me.

jain-shreyansh, 2023-08-05:
How can i read the data from the Abott Freestyle Libre Pro sensor,
Is there some specific protocol that should be used?
I identified that ISO15693 is being used, but i tried a few RFID readers for ISo15693 from play store, but that didn't work
it was not able to read the data

jain-shreyansh, 2023-08-05:
> Hi, I've been working on developing the Limitter device in India. We only have the "Libre Pro" sensors available here which stores complete data of 14 days. The sensor stores 15 minute trend data in one buffer and 14 days of historic data in the remaining memory blocks. I'm able to read the 15 minute trend data correctly. However the sensor NFC tag contains only 256 blocks and can store only 4-5 days of historic data. The remaining data is shown as factory locked. Hence I'm able to read only 4 days of historic data Any suggestions on how I could read the historic data of remaining 10 days ? Thanks !

Can you share how you were able to read the data?

gui-dos, 2023-08-06:
@jain-shreyansh:

@ MarekM60 ( R.I.P. :-( ) passed me some internal info and even a firmware dump of the Libre Pro (https://github.com/gui-dos/DiaBLE/blob/main/Reversing/Dumps/LibrePro-dump.bin) and I started writing a class to support its special FRAM and extended header layouts in iOS (https://github.com/gui-dos/DiaBLE/blob/main/DiaBLE/LibrePro.swift).

I was reported by some Indian guys that they could also connect to a Libre Pro successfully via a MiaoMiao but I never tested real sample and programmed in Java...

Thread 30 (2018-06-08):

LimiTTer return zeros

youssefmohsni, 2018-06-08:
Hi,
the program is returning 62C2000.... for the first value of "str" and 0.00 for the "Glucose level" and "15 minutes-trend: ". i wonder if there is any problem with the activation of the sensor because  i dont have the reader and play store don't allow me to download "liberlink".
Any idea to fix this problem?

Thanks !

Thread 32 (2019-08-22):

ESP32 version of LimiTTer (problem with BLE configuration...)

Philoul, 2019-08-22:
Hello,

I'm trying to make an ESP32 version of LimiTTer freestyle reader, but I can't connect my ESP32 to Xdrip+ (when I scan BT devices on my phone I see my ESP32 (BT name = "LimiTTer") and pair it), but impossible to see my ESP from xdrip+ to received my freestyle raw data (the "Scan Blustooth" don't find any device...

I think that my bluetooth configuration on my ESP32 is not ok but I don't know how to make it work... Can you help me please ?

my bluetooth configuration looks like

```
in header
#include "BluetoothSerial.h" //Header File for Serial Bluetooth, will be added by default into Arduino
BluetoothSerial ble_Serial; //Object for Bluetooth

in setup
    ble_Serial.begin("LimiTTer"); //Name of your Bluetooth Signal
    for (int i=0; ( (i < MAX_BLE_WAIT) && !(ble_Serial.hasClient()) ); i++)
    {
      delay(1000);
      Serial.print("Waiting for BLE connection ...");
      Serial.println("");
    }

in Send_Packet function
      ble_Serial.print(packet);
```

In setup, "ble_Serial.hasClient()" remains "false" (wrong use of it?)

When I arrive on the "ble_Serial.print(packet);" instruction (with a "correct xdrip packet"), I have a crash and reboot of my ESP
xDrip packet: 173647 216 100 17206

"Guru Meditation Error: Core  1 panic'ed (IllegalInstruction). Exception was unhandled."

I am sure my bluetooth configuration on my ESP32 LimiTTer code is not good but I don't know how to solve it...

Can you help me please ?

Philoul, 2019-08-30:
Hello,

I have found a solution:

My new Bluetooth configuration for ESP32 is :

in Header

```
#include <BLEDevice.h>
#include <BLEUtils.h>
#include <BLEServer.h>
#include <BLE2902.h>
#define MAX_BLE_WAIT 60 // Maximum bluetooth re-connect time in seconds
#define SERVICE_UART_UUID      "6E400001-B5A3-F393-E0A9-E50E24DCCA9E" // UART service UUID
#define CHARACTERISTIC_UUID_RX "6E400002-B5A3-F393-E0A9-E50E24DCCA9E"
#define CHARACTERISTIC_UUID_TX "6E400003-B5A3-F393-E0A9-E50E24DCCA9E"
BLEServer* pServer = NULL;
BLECharacteristic* pTxCharacteristic = NULL;
BLECharacteristic* pRxCharacteristic = NULL;
bool estConnecte = false;
bool etaitConnecte = false;

class EtatServeur : public BLEServerCallbacks
{
    void onConnect(BLEServer* pServer)
    {
      estConnecte = true;
    }

    void onDisconnect(BLEServer* pServer)
    {
      estConnecte = false;
    }
};

class CharacteristicUART : public BLECharacteristicCallbacks
{
    void onWrite(BLECharacteristic *pCharacteristique)
    {
      std::string rxValue = pCharacteristique->getValue();
      if (rxValue.length() > 0)
      {
        Serial.println("*********");
        Serial.print("Received Value: ");
        for (int i = 0; i < rxValue.length(); i++)
          Serial.print(rxValue[i]);
        Serial.println();
        Serial.println("*********");
      }
    }
};

```

Then in Setup :

```
  BLEDevice::init("LimiTTer");
  //BLEDevice::getAddress(); // Retrieve our own local BD BLEAddress
  pServer = BLEDevice::createServer();
  pServer->setCallbacks(new EtatServeur());

  BLEService *pServiceUART = pServer->createService(SERVICE_UART_UUID);
  pTxCharacteristic = pServiceUART->createCharacteristic(CHARACTERISTIC_UUID_TX, BLECharacteristic::PROPERTY_NOTIFY);
  // Create a BLE Descriptor : Client Characteristic Configuration (for indications/notifications)
  pTxCharacteristic->addDescriptor(new BLE2902());
  pRxCharacteristic = pServiceUART->createCharacteristic(CHARACTERISTIC_UUID_RX, BLECharacteristic::PROPERTY_WRITE);
  pRxCharacteristic->setCallbacks(new CharacteristicUART());

  pServiceUART->start();

  pServer->getAdvertising()->start();
  //BLEAdvertising *pAdvertising = pServer->getAdvertising();
  //pAdvertising->start();
  Serial.println("UART Over BLE start advertising");
  Serial.println("UART Over BLE wait connection");
    for (int i=0; ( (i < MAX_BLE_WAIT) && !estConnecte ); i++)
    {
      delay(1000);
      Serial.println("Waiting for BLE connection ...");
    }
```

and then for sending information (from String packet) :

```
      int Packet_Size = packet.length() + 1;
      char BlePacket[Packet_Size];
      packet.toCharArray(BlePacket, Packet_Size);
      pTxCharacteristic->setValue(BlePacket);
      pTxCharacteristic->notify();
```

It's a little more complicated but it works…

acnofsinger, 2019-12-07:
I have a ton of esp32s laying around.  Can you share any more information on your project?  NFC chip? Battery?  Thanks!

Philoul, 2019-12-07:
You can see my project here:
https://github.com/Philoul/LimitTer-ESP32

=> I used this reader for about 1 month, I made it before receiving my order (Miaomiao 2...)

=> My ESP32 ship is [MH-ET LIVE mini kit](http://mh.nodebb.com/topic/8/mh-et-live-minikit-for-esp32)
=> My NFC reader is [BM019 Solution Cubed](http://www.solutions-cubed.com/bm019/)
My batterie is not integrated and has not battery level monitoring (I used external power pack for charging smartphone)

For packaging I used an old Pump Patch Omnipod

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

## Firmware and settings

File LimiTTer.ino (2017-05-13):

/* LimiTTer sketch for the Arduino UNO/Pro-Mini.
   It scans the Freestyle Libre Sensor every 5 minutes
   and sends the data to the xDrip Android app. You can
   see the data in the serial monitor of Arduino IDE, too.
   If you want another scan interval, simply change the
   SLEEP_TIME value. 
     
   This sketch is based on a sample sketch for the BM019 module
   from Solutions Cubed.

   Wiring for UNO / Pro-Mini:

   Arduino          BM019           BLE-HM11
   IRQ: Pin 9       DIN: pin 2
   SS: pin 10       SS: pin 3
   MOSI: pin 11     MOSI: pin 5 
   MISO: pin 12     MISO: pin4
   SCK: pin 13      SCK: pin 6
   I/O: pin 2                   BLE_CHK: pin 15 
   I/O: pin 3                       VCC: pin 9 
   I/O: pin 5                        TX: pin 2
   I/O: pin 6                        RX: pin 4
*/

#include <SPI.h>
#include <SoftwareSerial.h>
#include <avr/sleep.h> 
#include <avr/power.h>
#include <avr/wdt.h>

#define MIN_V 3450 // battery empty level
#define MAX_V 4050 // battery full level
#define MAX_BLE_WAIT 80 // Maximum bluetooth re-connect time in seconds 
#define SLEEP_TIME 34 // SleepTime (7 points are about 1 minute)
#define MAX_NFC_READTRIES 10 // Amount of tries for every nfc block-scan

const int SSPin = 10;  // Slave Select pin
const int IRQPin = 9;  // Sends wake-up pulse for BM019
const int NFCPin1 = 7; // Power pin BM019
const int NFCPin2 = 8; // Power pin BM019
const int NFCPin3 = 4; // Power pin BM019
const int BLEPin = 3; // BLE power pin.
const int BLEState = 2; // BLE connection state pin
const int MOSIPin = 11;
const int SCKPin = 13;
byte RXBuffer[24];
byte NFCReady = 0;  // used to track NFC state
byte FirstRun = 1;
byte batteryLow;
int batteryPcnt;
long batteryMv;
int noDiffCount = 0;
int sensorMinutesElapse;
float lastGlucose;
float trend[16];

SoftwareSerial ble_Serial(5, 6); // RX | TX

void setup() {
    pinMode(IRQPin, OUTPUT);
    digitalWrite(IRQPin, HIGH); 
    pinMode(SSPin, OUTPUT);
    digitalWrite(SSPin, HIGH);
    pinMode(NFCPin1, OUTPUT);
    digitalWrite(NFCPin1, HIGH);
    pinMode(NFCPin2, OUTPUT);
    digitalWrite(NFCPin2, HIGH);
    pinMode(NFCPin3, OUTPUT);
    digitalWrite(NFCPin3, HIGH);
    pinMode(BLEPin, OUTPUT);
    digitalWrite(BLEPin, HIGH);
    pinMode(BLEState, INPUT);
    pinMode(MOSIPin, OUTPUT);
    pinMode(SCKPin, OUTPUT);

    Serial.begin(9600);

    long bleBaudrate[8] = {1200,2400,4800,9600,19200,38400,57600,115200};
    for (int i=0; i<8; i++)
    {
      ble_Serial.begin(bleBaudrate[i]);
      ble_Serial.write("AT");
      delay(500);
      char c = ble_Serial.read();
      char d = ble_Serial.read();
      if (c == 'O' && d == 'K')
        break;
    }
    delay(100);
    ble_Serial.write("AT+NAMELimiTTer");
    delay(500);
    ble_Serial.write("AT+RESET");
    delay(500);
        
    SPI.begin();
    SPI.setDataMode(SPI_MODE0);
    SPI.setBitOrder(MSBFIRST);
    SPI.setClockDivider(SPI_CLOCK_DIV32);

    delay(10);                      // send a wake up
    digitalWrite(IRQPin, LOW);      // pulse to put the 
    delayMicroseconds(100);         // BM019 into SPI
    digitalWrite(IRQPin, HIGH);     // mode 
    delay(10);
    digitalWrite(IRQPin, LOW);
}

void restartBLE() {
    digitalWrite(BLEPin, HIGH);
    digitalWrite(5, HIGH);
    digitalWrite(6, HIGH);
    delay(500);
    ble_Serial.write("AT+RESET");
    delay(500);
}

void SetProtocol_Command() {

  digitalWrite(SSPin, LOW);
  SPI.transfer(0x00);  // SPI control byte to send command to CR95HF
  SPI.transfer(0x02);  // Set protocol command
  SPI.transfer(0x02);  // length of data to follow
  SPI.transfer(0x01);  // code for ISO/IEC 15693
  SPI.transfer(0x0D);  // Wait for SOF, 10% modulation, append CRC
  digitalWrite(SSPin, HIGH);
  delay(1);
 
  digitalWrite(SSPin, LOW);
  while(RXBuffer[0] != 8)
    {
    RXBuffer[0] = SPI.transfer(0x03);  // Write 3 until
    RXBuffer[0] = RXBuffer[0] & 0x08;  // bit 3 is set
    }
  digitalWrite(SSPin, HIGH);
  delay(1);

  digitalWrite(SSPin, LOW);
  SPI.transfer(0x02);   // SPI control byte for read         
  RXBuffer[0] = SPI.transfer(0);  // response code
  RXBuffer[1] = SPI.transfer(0);  // length of data
  digitalWrite(SSPin, HIGH);

  if ((RXBuffer[0] == 0) & (RXBuffer[1] == 0))  // is response code good?
    {
    Serial.println("Protocol Set Command OK");
    NFCReady = 1; // NFC is ready
    }
  else
    {
    Serial.println("Protocol Set Command FAIL");
    NFCReady = 0; // NFC not ready
    }
}

void Inventory_Command() {

  digitalWrite(SSPin, LOW);
  SPI.transfer(0x00);  // SPI control byte to send command to CR95HF
  SPI.transfer(0x04);  // Send Receive CR95HF command
  SPI.transfer(0x03);  // length of data that follows is 0
  SPI.transfer(0x26);  // request Flags byte
  SPI.transfer(0x01);  // Inventory Command for ISO/IEC 15693
  SPI.transfer(0x00);  // mask length for inventory command
  digitalWrite(SSPin, HIGH);
  delay(1);
 
  digitalWrite(SSPin, LOW);
  while(RXBuffer[0] != 8)
    {
    RXBuffer[0] = SPI.transfer(0x03);  // Write 3 until
    RXBuffer[0] = RXBuffer[0] & 0x08;  // bit 3 is set
    }
  digitalWrite(SSPin, HIGH);
  delay(1);

  digitalWrite(SSPin, LOW);
  SPI.transfer(0x02);   // SPI control byte for read         
  RXBuffer[0] = SPI.transfer(0);  // response code
  RXBuffer[1] = SPI.transfer(0);  // length of data
  for (byte i=0;i<RXBuffer[1];i++)      
      RXBuffer[i+2]=SPI.transfer(0);  // data
  digitalWrite(SSPin, HIGH);
  delay(1);

  if (RXBuffer[0] == 128)  // is response code good?
    {
    Serial.println("Sensor in range ... OK");
    NFCReady = 2;
    }
  else
    {
    Serial.println("Sensor out of range");
    NFCReady = 1;
    }
 }
 
float Read_Memory() {

 byte oneBlock[8];
 String hexPointer = "";
 String trendValues = "";
 String hexMinutes = "";
 String elapsedMinutes = "";
 float trendOneGlucose;
 float trendTwoGlucose;
 float currentGlucose;
 float shownGlucose;
 float averageGlucose = 0;
 int glucosePointer;
 int validTrendCounter = 0;
 float validTrend[16];
 byte readError = 0;
 int readTry;
  
 for ( int b = 3; b < 16; b++) {
  readTry = 0;
  do {
  readError = 0;   
  digitalWrite(SSPin, LOW);
  SPI.transfer(0x00);  // SPI control byte to send command to CR95HF
  SPI.transfer(0x04);  // Send Receive CR95HF command
  SPI.transfer(0x03);  // length of data that follows
  SPI.transfer(0x02);  // request Flags byte
  SPI.transfer(0x20);  // Read Single Block command for ISO/IEC 15693
  SPI.transfer(b);  // memory block address
  digitalWrite(SSPin, HIGH);
  delay(1);
 
  digitalWrite(SSPin, LOW);
  while(RXBuffer[0] != 8)
    {
    RXBuffer[0] = SPI.transfer(0x03);  // Write 3 until
    RXBuffer[0] = RXBuffer[0] & 0x08;  // bit 3 is set
    }
  digitalWrite(SSPin, HIGH);
  delay(1);

  digitalWrite(SSPin, LOW);
  SPI.transfer(0x02);   // SPI control byte for read         
  RXBuffer[0] = SPI.transfer(0);  // response code
  RXBuffer[1] = SPI.transfer(0);  // length of data
 for (byte i=0;i<RXBuffer[1];i++)
   RXBuffer[i+2]=SPI.transfer(0);  // data
 if (RXBuffer[0] != 128)
     readError = 1;  
  digitalWrite(SSPin, HIGH);
  delay(1);
  
 for (int i = 0; i < 8; i++)
   oneBlock[i] = RXBuffer[i+3];
    
  char str[24];
  unsigned char * pin = oneBlock;
  const char * hex = "0123456789ABCDEF";
  char * pout = str;
  for(; pin < oneBlock+8; pout+=2, pin++) {
      pout[0] = hex[(*pin>>4) & 0xF];
      pout[1] = hex[ *pin     & 0xF];
  }
  pout[0] = 0;
  if (!readError)       // is response code good?
  { 
    Serial.println(str);
    trendValues += str;
  }
  readTry++;
  } while( (readError) && (readTry < MAX_NFC_READTRIES) );
  
 }
  readTry = 0;
  do {
  readError = 0;  
  digitalWrite(SSPin, LOW);
  SPI.transfer(0x00);  // SPI control byte to send command to CR95HF
  SPI.transfer(0x04);  // Send Receive CR95HF command
  SPI.transfer(0x03);  // length of data that follows
  SPI.transfer(0x02);  // request Flags byte
  SPI.transfer(0x20);  // Read Single Block command for ISO/IEC 15693
  SPI.transfer(39);  // memory block address
  digitalWrite(SSPin, HIGH);
  delay(1);
 
  digitalWrite(SSPin, LOW);
  while(RXBuffer[0] != 8)
    {
    RXBuffer[0] = SPI.transfer(0x03);  // Write 3 until
    RXBuffer[0] = RXBuffer[0] & 0x08;  // bit 3 is set
    }
  digitalWrite(SSPin, HIGH);
  delay(1);

  digitalWrite(SSPin, LOW);
  SPI.transfer(0x02);   // SPI control byte for read         
  RXBuffer[0] = SPI.transfer(0);  // response code
  RXBuffer[1] = SPI.transfer(0);  // length of data
 for (byte i=0;i<RXBuffer[1];i++)
   RXBuffer[i+2]=SPI.transfer(0);  // data
 if (RXBuffer[0] != 128)
     readError = 1;  
  digitalWrite(SSPin, HIGH);
  delay(1);
  
 for (int i = 0; i < 8; i++)
   oneBlock[i] = RXBuffer[i+3];
    
  char str[24];
  unsigned char * pin = oneBlock;
  const char * hex = "0123456789ABCDEF";
  char * pout = str;
  for(; pin < oneBlock+8; pout+=2, pin++) {
      pout[0] = hex[(*pin>>4) & 0xF];
      pout[1] = hex[ *pin     & 0xF];
  }
  pout[0] = 0;
  if (!readError)
    elapsedMinutes += str;
  readTry++;
  } while( (readError) && (readTry < MAX_NFC_READTRIES) );
      
  if (!readError)
    {
      hexMinutes = elapsedMinutes.substring(10,12) + elapsedMinutes.substring(8,10);
      hexPointer = trendValues.substring(4,6);
      sensorMinutesElapse = strtoul(hexMinutes.c_str(), NULL, 16);
      glucosePointer = strtoul(hexPointer.c_str(), NULL, 16);
             
      Serial.println("");
      Serial.print("Glucose pointer: ");
      Serial.print(glucosePointer);
      Serial.println("");
      
      int ii = 0;
      for (int i=8; i<=200; i+=12) {
        if (glucosePointer == ii)
        {
          if (glucosePointer == 0)
          {
            String trendNow = trendValues.substring(190,192) + trendValues.substring(188,190);
            String trendOne = trendValues.substring(178,180) + trendValues.substring(176,178);
            String trendTwo = trendValues.substring(166,168) + trendValues.substring(164,166);
            currentGlucose = Glucose_Reading(strtoul(trendNow.c_str(), NULL ,16));
            trendOneGlucose = Glucose_Reading(strtoul(trendOne.c_str(), NULL ,16));
            trendTwoGlucose = Glucose_Reading(strtoul(trendTwo.c_str(), NULL ,16));

            if (FirstRun == 1)
               lastGlucose = currentGlucose;
       
            if (((lastGlucose - currentGlucose) > 50) || ((currentGlucose - lastGlucose) > 50))
            {
               if (((lastGlucose - trendOneGlucose) > 50) || ((trendOneGlucose - lastGlucose) > 50))
                  currentGlucose = trendTwoGlucose;
               else
                  currentGlucose = trendOneGlucose;
            }
          }
          else if (glucosePointer == 1)
          {
            String trendNow = trendValues.substring(i-10,i-8) + trendValues.substring(i-12,i-10);
            String trendOne = trendValues.substring(190,192) + trendValues.substring(188,190);
            String trendTwo = trendValues.substring(178,180) + trendValues.substring(176,178);
            currentGlucose = Glucose_Reading(strtoul(trendNow.c_str(), NULL ,16));
            trendOneGlucose = Glucose_Reading(strtoul(trendOne.c_str(), NULL ,16));
            trendTwoGlucose = Glucose_Reading(strtoul(trendTwo.c_str(), NULL ,16));

            if (FirstRun == 1)
               lastGlucose = currentGlucose;
               
            if (((lastGlucose - currentGlucose) > 50) || ((currentGlucose - lastGlucose) > 50))
            {
               if (((lastGlucose - trendOneGlucose) > 50) || ((trendOneGlucose - lastGlucose) > 50))
                  currentGlucose = trendTwoGlucose;
               else
                  currentGlucose = trendOneGlucose;
            }
          }
          else
          {
            String trendNow = trendValues.substring(i-10,i-8) + trendValues.substring(i-12,i-10);
            String trendOne = trendValues.substring(i-22,i-20) + trendValues.substring(i-24,i-22);
            String trendTwo = trendValues.substring(i-34,i-32) + trendValues.substring(i-36,i-34);
            currentGlucose = Glucose_Reading(strtoul(trendNow.c_str(), NULL ,16));
            trendOneGlucose = Glucose_Reading(strtoul(trendOne.c_str(), NULL ,16));
            trendTwoGlucose = Glucose_Reading(strtoul(trendTwo.c_str(), NULL ,16));
            

            if (FirstRun == 1)
               lastGlucose = currentGlucose;
               
            if (((lastGlucose - currentGlucose) > 50) || ((currentGlucose - lastGlucose) > 50))
            {
               if (((lastGlucose - trendOneGlucose) > 50) || ((trendOneGlucose - lastGlucose) > 50))
                  currentGlucose = trendTwoGlucose;
               else
                  currentGlucose = trendOneGlucose;
            }
          }
        }  

        ii++;
      }
     
     for (int i=8, j=0; i<200; i+=12,j++) {
          String t = trendValues.substring(i+2,i+4) + trendValues.substring(i,i+2);
          trend[j] = Glucose_Reading(strtoul(t.c_str(), NULL ,16));
       }

    for (int i=0; i<16; i++)
    {
      if (((lastGlucose - trend[i]) > 50) || ((trend[i] - lastGlucose) > 50)) // invalid trend check
         continue;
      else
      {
         validTrend[validTrendCounter] = trend[i];
         validTrendCounter++;
      }
    }

    if (validTrendCounter > 0)
    { 
      for (int i=0; i < validTrendCounter; i++)
         averageGlucose += validTrend[i];
         
      averageGlucose = averageGlucose / validTrendCounter;
      
      if (((lastGlucose - currentGlucose) > 50) || ((currentGlucose - lastGlucose) > 50))
         shownGlucose = averageGlucose; // If currentGlucose is still invalid take the average value
      else
         shownGlucose = currentGlucose; // All went well. Take and show the current value
    }
    else
      shownGlucose = currentGlucose; // If all is going wrong, nevertheless take and show a value 

    if ((lastGlucose == currentGlucose) && (sensorMinutesElapse > 21000)) // Expired sensor check
      noDiffCount++;

    if (lastGlucose != currentGlucose) // Reset the counter
      noDiffCount = 0;

    if (currentGlucose != 0)
      lastGlucose = currentGlucose; 

    
    NFCReady = 2;
    FirstRun = 0;

    if (noDiffCount > 5)
      return 0;
    else  
      return shownGlucose;
    
    }
  else
    {
    Serial.print("Read Memory Block Command FAIL");
    NFCReady = 0;
    readError = 0;
    }
    return 0;
 }

float Glucose_Reading(unsigned int val) {
        int bitmask = 0x0FFF;
        return ((val & bitmask) / 8.5);
}

String Build_Packet(float glucose) {
  
// Let's build a String which xDrip accepts as a BTWixel packet

      unsigned long raw = glucose*1000; // raw_value
      String packet = "";
      packet = String(raw);
      packet += ' ';
      packet += "216";
      packet += ' ';
      packet += String(batteryPcnt);
      packet += ' ';
      packet += String(sensorMinutesElapse);
      Serial.println("");
      Serial.print("Glucose level: ");
      Serial.print(glucose);
      Serial.println("");
      Serial.print("15 minutes-trend: ");
      Serial.println("");
      for (int i=0; i<16; i++)
      {
        Serial.print(trend[i]);
        Serial.println("");
      }
      Serial.print("Battery level: ");
      Serial.print(batteryPcnt);
      Serial.print("%");
      Serial.println("");
      Serial.print("Battery mVolts: ");
      Serial.print(batteryMv);
      Serial.print("mV");
      Serial.println("");
      Serial.print("Sensor lifetime: ");
      Serial.print(sensorMinutesElapse);
      Serial.print(" minutes elapsed");
      Serial.println("");
      return packet;
}

void Send_Packet(String packet) {
   if ((packet.substring(0,1) != "0"))
    {
      Serial.println("");
      Serial.print("xDrip packet: ");
      Serial.print(packet);
      Serial.println("");
      ble_Serial.print(packet);
      delay(1000);
    }
   else
    {
      Serial.println("");
      Serial.print("Packet not sent! Maybe a corrupt scan or an expired sensor.");
      Serial.println("");
      delay(1000);
    }
  }

int readVcc() {
  // Read 1.1V reference against AVcc
  // set the reference to Vcc and the measurement to the internal 1.1V reference
  #if defined(__AVR_ATmega32U4__) || defined(__AVR_ATmega1280__) || defined(__AVR_ATmega2560__)
    ADMUX = _BV(REFS0) | _BV(MUX4) | _BV(MUX3) | _BV(MUX2) | _BV(MUX1);
  #elif defined (__AVR_ATtiny24__) || defined(__AVR_ATtiny44__) || defined(__AVR_ATtiny84__)
    ADMUX = _BV(MUX5) | _BV(MUX0);
  #elif defined (__AVR_ATtiny25__) || defined(__AVR_ATtiny45__) || defined(__AVR_ATtiny85__)
    ADMUX = _BV(MUX3) | _BV(MUX2);
  #else
    ADMUX = _BV(REFS0) | _BV(MUX3) | _BV(MUX2) | _BV(MUX1);
  #endif  
 
  delay(2); // Wait for Vref to settle
  ADCSRA |= _BV(ADSC); // Start conversion
  while (bit_is_set(ADCSRA,ADSC)); // measuring
 
  uint8_t low  = ADCL; // must read ADCL first - it then locks ADCH  
  uint8_t high = ADCH; // unlocks both
 
  batteryMv = (high<<8) | low;
 
  batteryMv = 1125300L / batteryMv; // Calculate Vcc (in mV); 1125300 = 1.1*1023*1000
  int batteryLevel = min(map(batteryMv, MIN_V, MAX_V, 0, 100), 100); // Convert voltage to percentage
  return batteryLevel;
}

void goToSleep(const byte interval, int time) {
 
 SPI.end();
 digitalWrite(MOSIPin, LOW);
 digitalWrite(SCKPin, LOW);
 digitalWrite(NFCPin1, LOW); // Turn off all power sources completely
 digitalWrite(NFCPin2, LOW); // for maximum power save on BM019.
 digitalWrite(NFCPin3, LOW);
 digitalWrite(IRQPin, LOW);
 digitalWrite(5, LOW);
 digitalWrite(6, LOW);
 digitalWrite(BLEPin, LOW);
 digitalWrite(BLEState, LOW);
 
 for (int i=0; i<time; i++) {
 MCUSR = 0;                         
 WDTCSR |= 0b00011000;               
 WDTCSR =  0b01000000 | interval;
 set_sleep_mode (SLEEP_MODE_PWR_DOWN);
 sleep_enable();
 sleep_cpu();           
 } 
}
ISR(WDT_vect) 
 {
 wdt_disable(); 
 }
  
void wakeUp() {
    
    sleep_disable();
    power_all_enable();
    wdt_reset();
    restartBLE();
    
    for (int i=0; ( (i < MAX_BLE_WAIT) && (digitalRead(BLEState) != HIGH) ); i++)
    {
      delay(1000);
      Serial.print("Waiting for BLE connection ...");
      Serial.println("");
    }    
    digitalWrite(NFCPin1, HIGH);
    digitalWrite(NFCPin2, HIGH);
    digitalWrite(NFCPin3, HIGH);
    digitalWrite(IRQPin, HIGH);
    SPI.begin();
    SPI.setDataMode(SPI_MODE0);
    SPI.setBitOrder(MSBFIRST);
    SPI.setClockDivider(SPI_CLOCK_DIV32);
    delay(10);                      
    digitalWrite(IRQPin, LOW);       
    delayMicroseconds(100);         
    digitalWrite(IRQPin, HIGH);      
    delay(10);
    digitalWrite(IRQPin, LOW);
    
    NFCReady = 0;
  }

void lowBatterySleep() {
 
 SPI.end();
 digitalWrite(MOSIPin, LOW);
 digitalWrite(SCKPin, LOW);
 digitalWrite(NFCPin1, LOW); // Turn off all power sources completely
 digitalWrite(NFCPin2, LOW); // for maximum power save on BM019.
 digitalWrite(NFCPin3, LOW);
 digitalWrite(IRQPin, LOW);
 digitalWrite(5, LOW);
 digitalWrite(6, LOW);
 digitalWrite(BLEPin, LOW);

 Serial.print("Battery low! LEVEL: ");
 Serial.print(batteryPcnt);
 Serial.print("%");
 Serial.println("");
 delay(100);

 // Switch LED on and then off shortly
    for (int i=0; i<10; i++) {
      digitalWrite(SCKPin, HIGH);
      delay(50);
      digitalWrite(SCKPin, LOW);
      delay(100);
    }
    
 MCUSR = 0;                         
 WDTCSR |= 0b00011000;               
 WDTCSR =  0b01000000 | 0b100001;
 set_sleep_mode (SLEEP_MODE_PWR_DOWN);
 sleep_enable();
 sleep_cpu();           
 sleep_disable();
 power_all_enable();
 wdt_reset(); 
}

void loop() {

  batteryPcnt = readVcc();
  if (batteryPcnt < 1)
    batteryLow = 1;
  while (batteryLow == 1)
  {
    lowBatterySleep();
    batteryPcnt = readVcc();
    if (batteryPcnt > 10)
    {
      batteryLow = 0;
      wakeUp();
      delay(100);
    }
  }
  if (NFCReady == 0)
  {
    SetProtocol_Command(); // ISO 15693 settings
    delay(100);
  }
  else if (NFCReady == 1)
  {
    for (int i=0; i<3; i++) {
    Inventory_Command(); // sensor in range?
    if (NFCReady == 2)
      break;
    delay(1000);
    }
    if (NFCReady == 1) {
    goToSleep (0b100001, SLEEP_TIME);
    wakeUp();
    delay(100); 
    }
  }
  else
  {
    String xdripPacket = Build_Packet(Read_Memory());
    Send_Packet(xdripPacket);
    goToSleep (0b100001, SLEEP_TIME);
    wakeUp();
    delay(100);
  }
}

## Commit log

2016-05-03 Corrected list of parts. Added some pics of skin mounting technique.
2016-05-14 Added baudrate auto-detection. Fixed showing randomly wrong low value. Android >= 5 is default now.
    [LimiTTer.ino]
2016-05-14 Changed wiring for Android >= 5 as default now. Added description of the intercept in calibration graph.
2016-05-26 Improved readings algorithm. Fixed buffer overflow bug.
    [LimiTTer.ino]
2016-08-05 Added battery level support by @TimMoritz
    You can now see the battery % level in xDrip+ and the mVolt value of the battery in "System Status".
    100% = 4.05V / 0% = 3.45V. At this voltage it falls very fast. To spare your battery the LimiTTer then
    goes into a lowBattery function and the Arduino blinks fast every 8 seconds. You have to charge it.
2016-09-17 Improved battery service life
2016-10-06 Add 3D printed case
    [bottom.scad, case_assembly.scad, case_print.scad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]
2016-10-06 Add print-ready STL-Files for the 3D printed case
    [case_assembly.stl, case_print.stl]
2016-11-25 Added sensor age counter and improved battery lifetime.
    You will see the remaining time (days) of the sensor in the graph. This feature works with xDrip+ nightly build >= 23.11.2016.
    LimiTTer doesn't make a full scan now to improve battery lifetime a little bit - only the trend area.
    [LimiTTer.ino]
2016-12-09 Fixed some bugs: serial output, after charging doesn't wake up, invalid glucose values.
    [LimiTTer.ino]
2016-12-10 Modified wiring schematic. Added mounting method (magnets).
2016-12-11 Fixed empty array bug.
    [LimiTTer.ino]
2016-12-17 Changed fetching method of shownGlucose
    Problem of the previous one was that there were noisy values when glucose is stable.
    This was because if the LimiTTer has detected that glucose is falling, it has taken the lowest
    value of all trend values - and the highest if rising. It looked like a "ping-pong" trend. Now
    it only takes and shows the recent trend value. If this is not valid, it will taken the next
    one and if not again the next-next one. If this value is still not valid (very corrupt scan), it will
    then taken and shown the average of all valid trend values.
    [LimiTTer.ino]
2017-03-11 Updated wiring for BLE state check of HM-Module
2017-03-11 Added BLE state check to improve battery lifetime and to avoid gaps.
    - You have to wire pin15 of the HM module with pin2 of Arduino. The deafult re-connect wait time is set to 80 seconds to avoid gaps. But if the reconnect is done faster by the phone it sends the packet immediately and goes to sleep to improve battery lifetime.
    - NFC scans every block up to 10 times if the response code is bad.
    - Removed Android 4 stuff in code and pdf.
    - Fixed false sensor lifetime value.
    [LimiTTer.ino]
2017-05-13 Fixed "LimiTTerAT+RESET" bug for some slowly HM-Modules
    [LimiTTer.ino]
